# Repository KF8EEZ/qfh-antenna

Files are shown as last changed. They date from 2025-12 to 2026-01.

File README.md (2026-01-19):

[Published page](https://kf8eez.github.io/qfh-antenna/)

# QFH Antenna Notes

Originally interested in the idea because of this [Cornell project](https://crowdfunding.cornell.edu/project/44450) that recommended one for a TinyGS ground site.

## Calculator

This calculator is referred to everywhere:
<http://jcoppens.com/ant/qfh/calc.en.php>

But now appears to be down. However the internet arhive has it: <https://web.archive.org/web/20250915134142/https://jcoppens.com/ant/qfh/calc.en.php>

## VHF and UHF

- <https://uuki.kapsi.fi/qha.html#:~:text=The%20Quadrifilar%20Helical%20Antenna%20(QHA,ever%20find%2C%20in%20all%20directions>

## Designs for 433 MHz

- <https://www.thingiverse.com/thing:5878204/>
- <https://www.printables.com/model/787650-fullwave-compact-qfh-antenna-for-433mhz-band>
- <https://www.printables.com/model/1293002-qfh-antenna-for-435-mhz-satellites>

## GPS design L1 band

- <https://forum.allaboutcircuits.com/threads/diy-gps-module-qfh-antenna.110474/>
- <https://lea.hamradio.si/~s53mv/navsats/analog.html>
- <http://schripsema.org/pa3hdf/projects/gpsantenna/gpsantenna.html>
- <https://www.scribd.com/doc/61729826/A-Home-Made-Helical-Antenna-for-a-GPS>
  - apparently a screenshot from another link that is dead. 
  - I got my own [screenshot](/refs/2025-12-12-helical-capture.png)

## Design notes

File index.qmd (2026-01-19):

---
title: "Quadrafilar Helicoidal Antenna"
---

## Introduction

There are references and design information for a QuadraFilar Helicoidal (QFH) antenna. 

There is a [live calcuator](/live/qfhcalc.qmd) based on the highly cited work of [@jcoppens]. 

Originally interested in the idea because of this [Cornell project](https://crowdfunding.cornell.edu/project/44450) that recommended one for a TinyGS ground site.

## Links to specific designs

### VHF

- <http://www.rocob.plus.com/main.html>

### VHF and UHF

- <https://uuki.kapsi.fi/qha.html> [@Niskanen2026]

### Designs for UHF 433 MHz

- <https://www.thingiverse.com/thing:5878204/>
- <https://www.printables.com/model/787650-fullwave-compact-qfh-antenna-for-433mhz-band>
- <https://www.printables.com/model/1293002-qfh-antenna-for-435-mhz-satellites>
- <https://www.printables.com/model/759022-qfa-qfh-antenna-70cm-band/comments>

### 868 MHz

- <https://github.com/cernohorsky/QFH-Antenna-868MHz>

### GPS design L1 band

- <https://forum.allaboutcircuits.com/threads/diy-gps-module-qfh-antenna.110474/>
- <https://lea.hamradio.si/~s53mv/navsats/analog.html> [MatjazVidmar2026]
- <http://schripsema.org/pa3hdf/projects/gpsantenna/gpsantenna.html>
- <https://www.scribd.com/doc/61729826/A-Home-Made-Helical-Antenna-for-a-GPS>
  - apparently a screenshot from another link that is dead. 
  - I got my own [screenshot](/refs/2025-12-12-helical-capture.png)

### 2450 MHz

- <https://www.thingiverse.com/thing:634205>

## References

:::{#refs}
:::

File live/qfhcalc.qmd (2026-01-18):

---
title: QFH antenna calculator
format: live-html
pyodide:
  autorun: true
  packages:
    - numpy
    - pandas
    - scipy
---

This cacluator is based on the work of [@jcoppens]. The original web-page is not online as of 2026-01-18 so I wrote this page to perform the calculations. This is live python code, you can edit the code blocks and rerun the calculations for different antenna parameters in order to customize to your scenario.

::: {.callout-warning}
In the original javascript version, the speed of light was set to $3\times 10^8$ m/s. This code uses a more accurate value of $2.997\times 10^8$ m/s from `scipy` so the results will not be identical. I created a [verify page](/static/verify.qmd) which uses the less precise value for validation.
:::

## Pyodide setup

```{pyodide}
#| autorun: true
import numpy as np
import pandas as pd
from scipy.constants import speed_of_light
```

## QFH design parameters

This is the code block where you should set the vlaues for your antenna design.

```{pyodide}
#| autorun: true
frequency_MHz = 137.5 # antenna operating frequency, freq
number_turns = 1.0 # number of turns to antenna, turns
length_of_one_turn = 1.0 # measured in wavelengths, [0.25, 0.5, 0.75, 1.0] rwavel
bending_radius_mm = 15.0 # wrad 
wire_diameter_mm = 3.0 # diam? , wdiam ?
width_height_ratio = 0.44 # ratio
```

## Results

### Wavelength in freespace

```{pyodide}
#| autorun: true
wavelength = speed_of_light/(frequency_MHz*1e6) # meters, wavel
print(f'Wavelength = {wavelength} meters')
```

### Compensated wavelength

This is a correction for the size of the wire. 

```{pyodide}
#| autorun: true
wire_diameter_effective_mm = wire_diameter_mm
if wire_diameter_effective_mm > 15.0:
    wire_diameter_effective_mm = 15.0

def delta_length(diam):

    # this is a table of corrections copied directly from qfhcalc.js
    # the index appears to translate directly to the wire diameter in mm
    tbl = np.array([1.045, 1.053, 1.060, 1.064, 1.068, 1.070, 1.070, 1.071, 
             1.071, 1.070, 1.070, 1.070, 1.070, 1.069, 1.069, 1.068,
	     1.067])
    intv = int(np.floor(diam))
    dl = tbl[intv] +  (tbl[intv+1]-tbl[intv])*(diam-intv)
    return dl

compensated_wavelength = wavelength * delta_length(wire_diameter_effective_mm) # wavelc

print(f'Compensated wavelength = {compensated_wavelength} meters')
```

### Bending correction

```{pyodide}
#| autorun: true
#| label: bending-correction
bending_correction_mm = 2*bending_radius_mm - np.pi*bending_radius_mm/2.0 # bcorr

print(f'Bending correction = {bending_correction_mm} millimeters')
```

### Optimal conductor diameter

This is a confusing calculation in the original because it depends upon the conductor diameter.

```{pyodide}
#| autorun: true
#|label: optimal-conductor
# factor of 1000 converts meter to millimeter
# factor of 0.0088 is in original code, don't know what it is
optimal_diameter_mm = 0.0088 * compensated_wavelength * 1000.0

print(f'Optimal condcutor diameter = {optimal_diameter_mm} millimeters')
```

### Larger loop

This is also referred to as loop 1

```{pyodide}
#| autorun: true
#| label: larger-loop-values
total_length_lg = compensated_wavelength * 1.026 # total1
total_compensated_length_lg = total_length_lg + 4 * bending_correction_mm/1000 # total1c
horizontal_separator_lg =  0.5 *  total_compensated_length_lg/ \
           (1 + np.sqrt(1/width_height_ratio**2 + (number_turns*np.pi)**2)) # rad1, D1=
horizontal_compensated_separator_lg = horizontal_separator_lg - 2*bending_radius_mm/1000.0 # rad1c, D1C=
vertical_separation_lg = (total_compensated_length_lg - 2*horizontal_separator_lg)/2 # vert1
vertical_separation_compensated_lg = vertical_separation_lg - 2*bending_radius_mm/1000.0 # vert1c
internal_diameter_lg = horizontal_separator_lg - wire_diameter_mm/1000.0 #idiam1, Di1=
height_lg = horizontal_separator_lg / width_height_ratio # height1, H1=
```

```{pyodide}
#| autorun: true
#| label: print-large-loop-values
data_lg = {
    'Names': [
        'Total length',
        'Vertical separator',
        'Total compensated length',
        'Compensated vertical separation',
        'Antenna height',
        'Internal diameter',
        'Horizontal separator',
        'compensated horizontal separation',
        ],
    'Labels' :[
        '',
        '',
        '',
        '',
        'H1=',
        'Di1=',
        'D1=',
        'Dc1=',
        ],
    'Values': [
        total_length_lg,
        vertical_separation_lg,
        total_compensated_length_lg,
        vertical_separation_compensated_lg,
        height_lg,
        internal_diameter_lg,
        horizontal_separator_lg,
        horizontal_compensated_separator_lg,
        ]
    }
df = pd.DataFrame(data_lg)
df
```

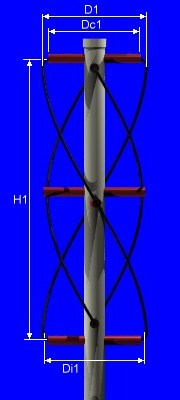
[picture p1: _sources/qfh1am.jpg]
Diagram of dimensions for larger loop from [@jcoppens]


### Smaller loop

This is also referred to as loop 2. These are basically the same calculations except for the 0.975 factor instead of the 1.026 factor.

```{pyodide}
#| autorun: true
#| label: smaller-loop-values
total_length_sm = compensated_wavelength * 0.975 # total2
total_compensated_length_sm = total_length_sm + 4 * bending_correction_mm/1000 # total2c
horizontal_separator_sm =  0.5 *  total_compensated_length_sm/ \
           (1 + np.sqrt(1/width_height_ratio**2 + (number_turns*np.pi)**2)) # rad2, D2=
horizontal_compensated_separator_sm = horizontal_separator_sm - 2*bending_radius_mm/1000.0 # rad2c, D2c=
vertical_separation_sm = (total_compensated_length_sm - 2*horizontal_separator_sm)/2 # vert2
vertical_separation_compensated_sm = vertical_separation_sm - 2*bending_radius_mm/1000.0 # vert2c
internal_diameter_sm = horizontal_separator_sm - wire_diameter_mm/1000.0 #idiam1, Di2=
height_sm = horizontal_separator_sm / width_height_ratio # height2, H2=
```

```{pyodide}
#| autorun: true
#| label: print-small-loop-values
data_sm = {
    'Names': [
        'Total length',
        'Vertical separator',
        'Total compensated length',
        'Compensated vertical separation',
        'Antenna height',
        'Internal diameter',
        'Horizontal separator',
        'compensated horizontal separation',
        ],
    'Labels' :[
        '',
        '',
        '',
        '',
        'H2=',
        'Di2=',
        'D2=',
        'Dc2=',
        ],
    'Values': [
        total_length_sm,
        vertical_separation_sm,
        total_compensated_length_sm,
        vertical_separation_compensated_sm,
        height_sm,
        internal_diameter_sm,
        horizontal_separator_sm,
        horizontal_compensated_separator_sm,
        ]
    }
df = pd.DataFrame(data_sm)
df
```

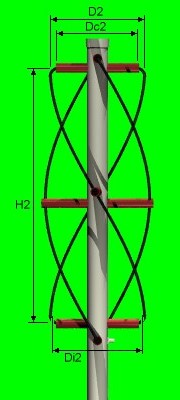
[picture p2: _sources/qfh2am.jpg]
Diagram of dimensions for smaller loop from [@jcoppens]


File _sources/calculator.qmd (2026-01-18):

This is based on <https://jcoppens.com/ant/qfh/calc.en.php> which now seems to be down but can be found on the internet archive at <https://web.archive.org/web/20250915134142/https://jcoppens.com/ant/qfh/calc.en.php>.

For testing of javascript in original, I used this page <https://jsconsole.com/>

## Python imports

Compute wavelength. Original website used $c=3\times 10^8$ m/s. For testing I'm using that value here. 

```{python}
import numpy as np
import pandas as pd
# from scipy.constants import speed_of_light
speed_of_light = 3e8 # m/s to match original for testing
```

## Design parameters

```{python}
frequency_MHz = 137.5 # antenna operating frequency, freq
number_turns = 1.0 # number of turns to antenna, turns
length_of_one_turn = 1.0 # measured in wavelengths, [0.25, 0.5, 0.75, 1.0] rwavel
bending_radius_mm = 15.0 # wrad 
wire_diameter_mm = 3.0 # diam? , wdiam ?
width_height_ratio = 0.44 # ratio
```

## Results

### Wavelength in free space

```{python}
wavelength = speed_of_light/(frequency_MHz*1e6) # meters, wavel
```

### Compensated wavelength

This is a correction for the size of the wire. 

```{python}
wire_diameter_effective_mm = wire_diameter_mm
if wire_diameter_effective_mm > 15.0:
    wire_diameter_effective_mm = 15.0
```

```{python}
#| label: compute-compensated-wavelength
def delta_length(diam):

    # this is a table of corrections copied directly from qfhcalc.js
    # the index appears to translate directly to the wire diameter in mm
    tbl = np.array([1.045, 1.053, 1.060, 1.064, 1.068, 1.070, 1.070, 1.071, 
             1.071, 1.070, 1.070, 1.070, 1.070, 1.069, 1.069, 1.068,
	     1.067])
    intv = int(np.floor(diam))
    print(intv,tbl[intv])
    dl = tbl[intv] +  (tbl[intv+1]-tbl[intv])*(diam-intv)
    return dl

compensated_wavelength = wavelength * delta_length(wire_diameter_effective_mm) # wavelc
    
```

### Bending correction

```{python}
#| label: bending-correction
bending_correction_mm = 2*bending_radius_mm - np.pi*bending_radius_mm/2.0 # bcorr
```

### Optimal conductor diameter

This is a confusing calculation in the original because it depends upon the conductor diameter.

```{python}
#|label: optimal-conductor
# factor of 1000 converts meter to millimeter
# factor of 0.0088 is in original code, don't know what it is
optimal_diameter_mm = 0.0088 * compensated_wavelength * 1000.0
```

### Larger loop

This is also referred to as loop 1

```{python}
#| label: larger-loop-values
total_length_lg = compensated_wavelength * 1.026 # total1
total_compensated_length_lg = total_length_lg + 4 * bending_correction_mm/1000 # total1c
horizontal_separator_lg =  0.5 *  total_compensated_length_lg/ \
           (1 + np.sqrt(1/width_height_ratio**2 + (number_turns*np.pi)**2)) # rad1, D1=
horizontal_compensated_separator_lg = horizontal_separator_lg - 2*bending_radius_mm/1000.0 # rad1c, D1C=
vertical_separation_lg = (total_compensated_length_lg - 2*horizontal_separator_lg)/2 # vert1
vertical_separation_compensated_lg = vertical_separation_lg - 2*bending_radius_mm/1000.0 # vert1c
internal_diameter_lg = horizontal_separator_lg - wire_diameter_mm/1000.0 #idiam1, Di1=
height_lg = horizontal_separator_lg / width_height_ratio # height1, H1=
```

```{python}
#| label: print-large-loop-values
data_lg = {
    'Names': [
        'Total length',
        'Vertical separator',
        'Total compensated length',
        'Compensated vertical separation',
        'Antenna height',
        'Internal diameter',
        'Horizontal separator',
        'compensated horizontal separation',
        ],
    'Labels' :[
        '',
        '',
        '',
        '',
        'H1=',
        'Di1=',
        'D1=',
        'Dc1=',
        ],
    'Values': [
        total_length_lg,
        vertical_separation_lg,
        total_compensated_length_lg,
        vertical_separation_compensated_lg,
        height_lg,
        internal_diameter_lg,
        horizontal_separator_lg,
        horizontal_compensated_separator_lg,
        ]
    }
df = pd.DataFrame(data_lg)
df
```

### Smaller loop

This is also referred to as loop 2. These are basically the same calculations except for the 0.975 factor instead of the 1.026 factor.

```{python}
#| label: smaller-loop-values
total_length_sm = compensated_wavelength * 0.975 # total2
total_compensated_length_sm = total_length_sm + 4 * bending_correction_mm/1000 # total2c
horizontal_separator_sm =  0.5 *  total_compensated_length_sm/ \
           (1 + np.sqrt(1/width_height_ratio**2 + (number_turns*np.pi)**2)) # rad2, D2=
horizontal_compensated_separator_sm = horizontal_separator_sm - 2*bending_radius_mm/1000.0 # rad2c, D2c=
vertical_separation_sm = (total_compensated_length_sm - 2*horizontal_separator_sm)/2 # vert2
vertical_separation_compensated_sm = vertical_separation_sm - 2*bending_radius_mm/1000.0 # vert2c
internal_diameter_sm = horizontal_separator_sm - wire_diameter_mm/1000.0 #idiam1, Di2=
height_sm = horizontal_separator_sm / width_height_ratio # height2, H2=
```

```{python}
#| label: print-small-loop-values
data_sm = {
    'Names': [
        'Total length',
        'Vertical separator',
        'Total compensated length',
        'Compensated vertical separation',
        'Antenna height',
        'Internal diameter',
        'Horizontal separator',
        'compensated horizontal separation',
        ],
    'Labels' :[
        '',
        '',
        '',
        '',
        'H2=',
        'Di2=',
        'D2=',
        'Dc2=',
        ],
    'Values': [
        total_length_sm,
        vertical_separation_sm,
        total_compensated_length_sm,
        vertical_separation_compensated_sm,
        height_sm,
        internal_diameter_sm,
        horizontal_separator_sm,
        horizontal_compensated_separator_sm,
        ]
    }
df = pd.DataFrame(data_sm)
df
```

## Original

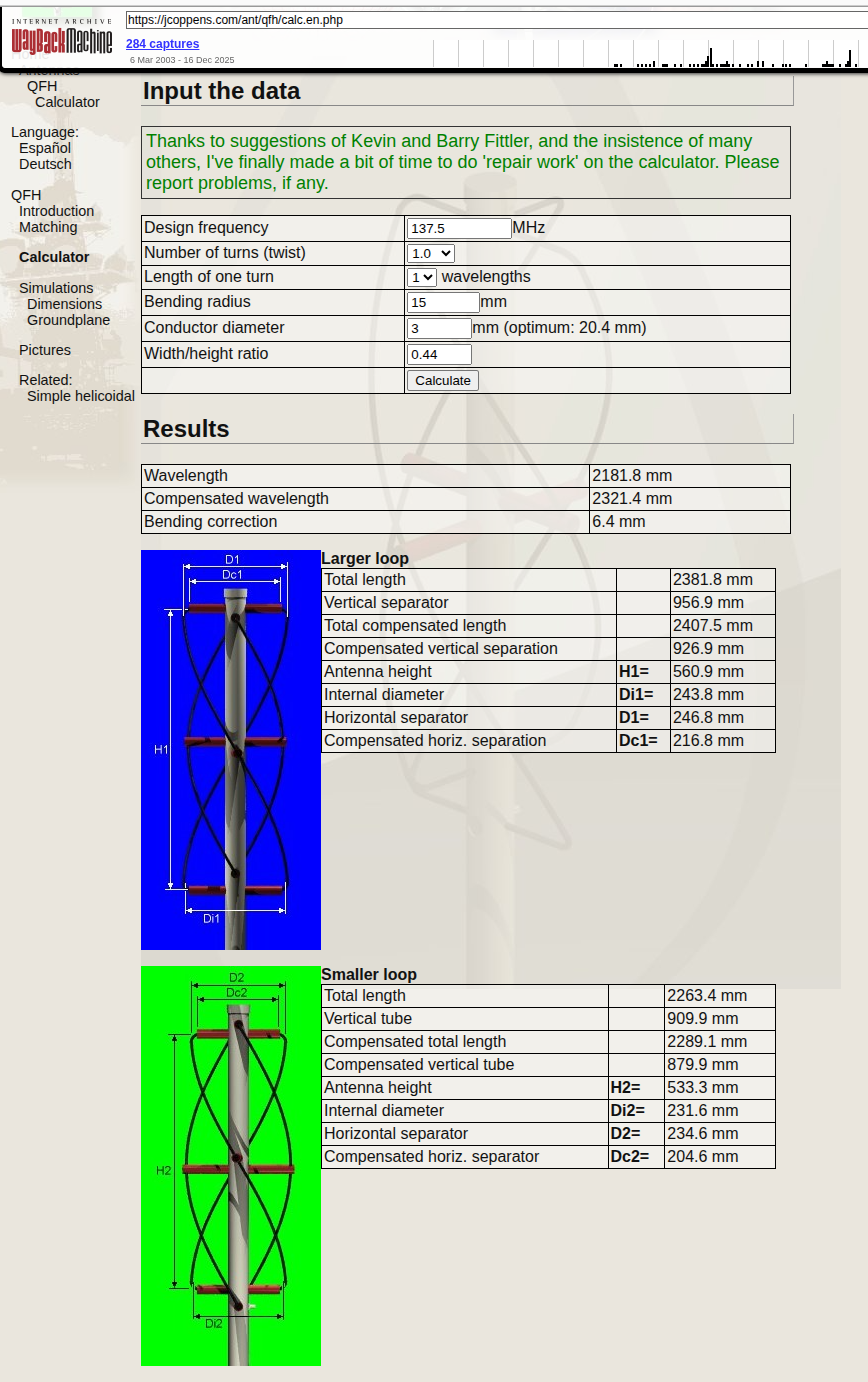
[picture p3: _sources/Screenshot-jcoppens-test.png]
Screenshot of original page captured by internet archive using the same parameters in this page.


### Legend of parameters copied from original

This calculator generates a lot of data! Take care in the use of the information in order not to make mistakes...
Here's a little explanation:

- Design frequency
  - Evident?
- Number of turns (twist)
  - What's the twist of the antenna? (normally 0.5 (180 degrees)
- Length of one turn
  - A few variations of the antenna exist. Normally the circumference (length of the loop) is 1 wavelength, but 1.5 wavelength and 2 wavelength versions exist.
- Bending diameter
  - As it's impossible to bend the corner abruptly at 90 degrees, this value is needed for the calculations. It's measured from the bending center to the center of the tube.
- Conductor diameter
  - External diameter of the tube or coax cable.
- Diameter/height ratio
  - Most frequently this ratio is 0.44, but slightly lower values (0.3 to 0.4) give better horizon coverage.
- Wavelength
  - Wavelength, corresponding to the selected frequency.
- Compensated wavelength
  - Wavelength, compensated according to the conductor diameter.
- Bending correction
  - Correction value needed according to the bending diameter.
- Total length
  - Total length of the loop, before compensation.
- Total loop cmpensated length
  - Total length of the loop, compensated for the bending effect, and the fact that the loop must be slightly larger (or smaller). This is the amount of tubing necessary for this loop.
- Compensated vertical separation
  - Vertical separation (without the 'bends').
- Compensated horizontal separation
  - This is in fact the horizontal part without the 'bends', and corresponds to the horizontal pipe necessary to support the cable.
- Antenna height
  - Height of the loop (twisted!).
- Internal diameter
  - The diameter of the (imaginary) cylinder on which the loop would be wound.

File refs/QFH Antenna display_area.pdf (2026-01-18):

## QFH Antenna (The Quadrifilar Helical antenna)

provides circular polarization and complete hemispherical reception, which is precisely what is needed to receive the polar orbiting weather satellites, and as a

### 2 meter antenna it will receive horizontal, vertical and clockwise circular

polarization’s from all directions. Fig 1. illustrates the antenna which consists of two vertical loops at right angles to each other, resonant at slightly different frequencies, twisted into a half turn helix. Correctly made it will provide true
all round coverage with circular polarization at all angles. The usual crossed
dipoles and reflectors used for satellite reception only provide circular polarization directly upwards when the signal strength is high anyway, at low angles when maximum sensitivity is required the polarization is linear, losing 3 dB on the circularly polarized satellite signal. In addition Quadrature feed of crossed dipoles to achieve circular polarization is beautiful in theory and almost impossible to achieve in practice.

Bob Cobey G0HPO an avid weather satellite fan first made one in this area and reported phenomenal results, even inside the roof space of his bungalow. Good noise free pictures were received from Greenland through to Algeria.

The R.I.G articles by Mark Pepper Rig 37 and Chris Van Lint (Rig 44) and also in QST are based on the original work by NASA featured in the ARRL Antenna handbook. There are a number of practical problems in the design which have been addressed and solved over many weeks of computer modelling and prototype construction.

The computer generated (Azimuth & Elevation) polar diagrams are of course perfection and a series of actual measurements of the horizontal and vertical patterns were undertaken on the final design to confirm the computer results.

The measured vertical and horizontal polar diagrams using clockwise polarization, were produced using the latest version of a program by Bob Freeth ( G4HFQ ) called PolarPlot. The Windows 95/98 & 2000 version of the program is now available for download by visiting his page using the links in the right hand column.

Vertical and horizontal polarization’s are 3dB down on clockwise as expected and the horizontal pattern is still circular. The polar diagram in the vertical plane is particularly useful, showing very little reception from below, thus reducing the formation of nulls caused

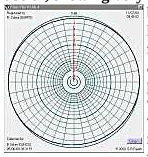
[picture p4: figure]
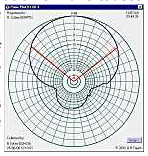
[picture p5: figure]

by ground reflections. There are no nulls in the horizontal pattern at any polarization. Allowing for slight distortion in actual measurement of antenna performance, caused by the usual site problems the measured plots and measured gain were identical to the computer generated plots which was particularly satisfying, given the inherent difficulty in modelling a helix in XYZ format for the computer.

The major problem is how to make the beast, and particularly how to make it weatherproof. Firstly the dimensions given by the NASA based articles need to be adjusted for weather satellite and 2 meter frequencies. The diameter of tubing used in the ARRL handbook works

Larger Views may be seen by Clicking on the side index or the pictures

1/18/26, 2:30 PM | QFH Antenna display_area
www.rocob.plus.com/main.html | 1/4

out to 19mm at 137 MHz and dimensions show the INSIDE diameter of the helix. Conversion to 8mm tubing which is a much more sensible size at 137 and 145 MHz was not just a question of simple scaling. As stated in the book a quadrature-phase current relationship is required between the two loops. This is achieved by making one loop larger than the desired frequency resonant length and therefore inductive, while the other loop is smaller and therefore capacitive. Correct resonance of each loop means that a circular pattern may be achieved by simply connecting the two loops in parallel. This is confirmed in practice when the SWR dips once only at the required frequency. It is all too easy to get a double hump response which is incorrect, and will show a figure of eight pattern rather than a true circular horizontal polar diagram. The sizes shown have been confirmed by computer modelling and actual measurements on the prototype, and do not conform with the book figures. In particular the helix should be the same diameter throughout its length and therefore the length of the arms forming the helix is important. The formula for this length
is | where 'r' is the radius and 'h' the height of the helix.

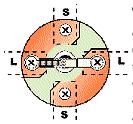
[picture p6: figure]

The major problem was how to make weatherproof the connections at top and bottom of the helix. The connections at the top of the helix in the original design were almost impossible, as the connection had to be made to the ends of four tubes, two of which were 24mm below the top two, with all inside the support mast. Using the computer modelling program, various connection methods were tried to establish a sensible method without compromising the performance. It proved possible to slope the tops of the small loop so that all four tube ends were in a common plane at the top of the mast where they can be reached. The final method uses a small piece of PC board very simply made, shown in Fig 2, which gives good mechanical and electrical connections.

Fig 3 illustrates the original infinite balun arrangement which provides an
elegant way of bringing the feeder away from the antenna at a voltage null.
This is totally impossible to make if the antenna is made using a central non metallic support mast (as it must be at 137 MHz) when the connections would have to be made inside the mast.
One solution to this was to make the antenna from two continuous lengths of
copper tubing with a small diameter coaxial feeder brought through a hole in
the feed tube at the null point and connected at the top. This would still be difficult as the feeder entry hole would be inside the support mast. In practice moving the hole a few millimetres to bring the feeder outside the mast solves the mechanical problem and since the current in the lower half of the loop is substantially constant, still provides a good enough voltage null to get the feeder away without affecting the performance of the antenna. The outer braiding of the coax need not be connected to the tube at the point of exit thus preserving the integrity of the coax for weatherproofing. Several antennas were built using this method and were perfectly satisfactory electrically, but construction was extremely difficult. Various methods of actually making the Helix were tried, the use of coaxial cable as in previous designs is acceptable as an indoor antenna but weatherproofing for outside use is almost impossible. 8mm soft copper central heating tube available from the plumbing department of all DIY shops and builders merchants proved to be the easiest to use. Bending tubing by hand is not satisfactory unless the resulting kinks and flattening are acceptable. The elegant way is to use small copper elbows at the corners but it proved totally impossible to insert RG58 coax into the tube after the elbows had been sweated into position and sweating after the coax was inside was not a good idea.
While the original balun design is perfection electrically, it is the main cause of the construction difficulties, and some other type of balun was required. The use of a simple choke balun proved to be the answer and solved all the mechanical problems.
Fig.4 illustrates the feed method where the necessary isolating choke is formed from winding

### 4 turns of the feeder cable round the support mast. No longer does the antenna have to be

www.rocob.plus.com/main.html | 2/4

constructed from coaxial cable or have coaxial cable threaded through tubes, and it CAN BE MADE with identical performance to the original NASA design. Performance checks comparing the original design with the new system showed no differences, in particular the feeder was still dead.

CONSTRUCTION

Fig.5 shows the final design using 8mm copper tube with dimensions shown as cut lengths for 137.55 MHz allowing for the length of the copper elbows. Any change in tube size will require different dimensions. Make no mistake, the dimensions are important. This antenna will work after a fashion with almost any slip shod construction but then the polar diagram will not be circular and its a matter of luck whether the maximum lobes are in a useful position.

Mark out the plastic support mast using the template Fig 6 to
ensure that the holes are at right angles. Drill the 4 x 8mm holes,
two at the top at right angles in the same plane and the two lower down at right angles spaced 24mm. Then drill the 7 mm hole near the top of the mast for the cable entry as shown in fig 4.
Carefully straighten the roll of 8mm tube. This is best done by rolling it out onto the floor keeping the coil vertical. Cut the tube into lengths to the dimensions shown and drill the appropriate holes for the self tapping screws in the ends of the top horizontal sections.
Firstly make the top part of the antenna with the cable and connections. Feed the coax through the hole into the mast and then out of the top threading it through the hole in the centre of the PC board. The top 4 horizontal tubes can then be assembled, the two horizontal tubes forming the top of the smaller of the two loops should be carefully bent 24mm see Fig.

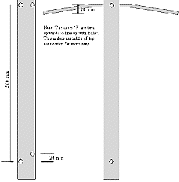
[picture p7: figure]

### 7. The PC board should be mounted copper side down to connect

with the copper of the tubes, thus avoiding any dissimilar metal
problems with the possible zinc plating of the screws. Four turns
of the feeder cable should now be wound around the support mast to form the balun and taped into position.
Next mount the lower 2 horizontal sections through the mast positioning them centrally. The helix can now be formed. First place the copper elbows into position but do not solder at this stage. Carefully bend the appropriate lengths of tube to form the
helix. Remember the helix should be wound ANTICLOCKWISE
as seen from the top (and the bottom for that matter) to provide
clockwise polarization as used on the weather satellites. Final soldering into place can now be done using a small gas torch, the plumbers’ trick of applying flux to the copper tubes before fitting onto the elbows will ensure quick and easy flow of solder. The connections at the top require an end cap for weatherproofing and although the appropriate pieces can be obtained from the same source as the plastic tube the user may well find a plastic jar cover of suitable size to do the job.

PLEASE REMEMBER THAT THIS TYPE OF ANTENNA PRESENTS A DC SHORT CIRCUIT AND PRECAUTIONS SHOULD BE TAKEN IF YOUR RECEIVER OUTPUTS A VOLTAGE TO FEED A PRE-AMP.

Cut lengths in mm for 137.55 MHz, using 8mm Central Heating tube & 90 deg elbows.

LOOP | A | B | C | D | E | F | Ht. | PERI
Large | 2 x 812 | 1 x 374 | 2 x 182 | | | | 560 | 2418
www.rocob.plus.com/main.html | 3/4

Small | 2 x 758 | 1 x 356 | 2 x 178 | 512 | 2284

Parts List (Cost less than £15 from most Hardware Stores)

### 5 mtr x 8 mm Copper Tube (Mini Bore Central Heating Pipe) 8 x 8 mm 90 Deg. End Fed Elbows ( Qty. 8 required ) 1 meter of 32 mm PVC waste pipe

Etched PC board or Strip board with strips cut to suit.
4 Self start screws to secure PCB and feed.
Suitable length of UR43 or RG58 Coaxial cable for Balun and feed

© G0HPO July 2000 - September 2003

www.rocob.plus.com/main.html | 4/4

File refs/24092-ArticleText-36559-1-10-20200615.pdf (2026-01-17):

International Journal of Advance Science and Technology Vol. 29, No. 10S, (2020), pp. 7694-7705

ISSN: 2005-4238 IJAST | 7694
Copyright ⓒ 2020 SERSC

### SDR Based Ground Station for Image Reception from Weather Satellites

Ajith Kumar Joel T¹

, Pavan Kalyan Reddy Y²

, Charan Yadav NP³

, Chandan MN⁴
, Dr.
M.Devanathan⁵
1,2,3School of ECE REVA University Bangalore, India Asst. Prof., School of ECE REVA University Bangalore, India ajith1081999@gmail.com¹

, pavankalyan29787@gmail.com²

, npcharan77@gmail.com³
chandanmn183@gmail.com⁴

, Devanathan.m@reva.edu.in⁵

Abstract
From the specific view of space, sophisticated Low Earth Orbit (LEO) satellites provide us with information on cloud movements, precipitation, land and sea surface temperatures. These satellites are fascinating as they continuously transmit an image signal that is easy to decipher of what they are actually looking at. This data is useful to predict weather and rainfall. The main purpose of this work is to develop an inexpensive ground station for receiving the images from these satellites and give a rough prediction of weather and rainfall. Software Defined Radio (SDR) was used for the reception of these signals along with V-Dipole, QFH Antenna and several open source software’s. So far this work is successful in receiving signal from 40+ satellite passes of the National Oceanic and Atmospheric Administration’s (NOAA) and METEOR-M2 satellites over the location Bangalore, India (Grid: MK83SC) and decoded the same to obtain real time images as seen by the satellite. The images obtained were further analyzed for rough weather predictions over the above mentioned location.

Keywords: Automatic Picture Transmission (APT), Low Rate Picture Transmission (LRPT), Software Defined Radio (SDR), Quadrifilar Helix (QFH) Antenna.

### 1. INTRODUCTION

The National Oceanic and Atmospheric Administration’s (NOAA) is an American scientific agency which has launched 19 satellites that focuses on forecasting changes in climate, weather, oceans and coasts. At present NOAA-15, NOAA-18 and NOAA-19 are geosynchronous satellites active with Automatic Picture Transmission (APT) feature, orbiting at an altitude around 830km. These satellites are equipped with series of instruments and one of the sensor which is AVHRR (Advanced Very High-Resolution Radiometer) has a feature to detect the reflection of electromagnetic waves by clouds, surface waters and objects on the surface of the earth. The AVHRR has 6 detectors operating on a channel of wavelengths ranging from visible to thermal infrared. The live weather images are broadcasted by the APT signals. METEOR-M2 is a Russian weather satellite launched to monitor atmosphere, sea temperatures, humidity, ice conditions and clouds. Meteor-M2 is currently active with LRPT (Low Rate Picture Transmission) feature. The objective is to set up a low cost base station by using a Software Defined Radio (SDR) along with a suitable antenna (Quadrifilar Helix Antenna, V Dipole Antenna ) to receive the signals from NOAA and Meteor-M2 satellites and decode the same using several open source software's (SDR#, WxToImg, Orbitron, LRPT Decoder) to obtain real time images when the satellite is overhead.

### 2. AUTOMATIC PICTURE TRANSMISSION(APT)

The Automatic Picture Transmission (APT) is an analog transmission system developed to get data in the form of pictures from weather satellites. Over five decades, it has helped to get real-time image data for low-cost base stations across many parts of the world. APT system has 2 image channels i.e. Infrared and Near Infrared/Visible Channel. The image reception starts when the receiver is within the radio range. For about 8-15 minutes the satellite is within the radio range. When both, the receiver and satellite frequencies are matched, with the help of unsophisticated receivers the final output is obtained.
Frequency range – 137-138 MHz

Bandwidth - 35 KHz (to overcome Doppler Shift) Modulation – Wideband FM (WFM)
Currently, there are only 3 NOAA satellites i.e. NOAA-15, NOAA-18 and NOAA-19 which transmit APT signals.

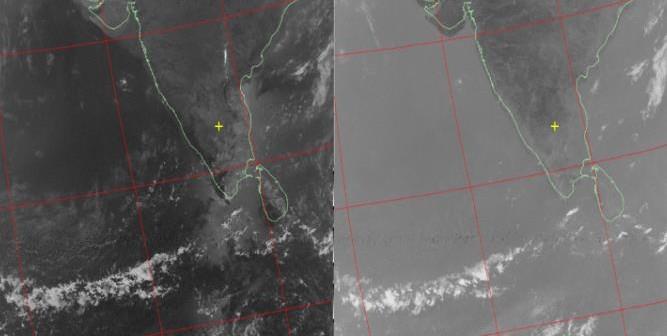
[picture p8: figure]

Fig 1: The 2 channel APT image system

### 3. LOW RATE PICTURE TRANSMISSION (LRPT)

The Low Rate Picture Transmission (LRPT) is a digital transmission system, which is used by the Meteor-M2 satellite to transmit the signal. This system was introduced as a replacement for APT. APT system had only 2 image channels (Infrared and Near Infrared/Visible Channel) which were at reduced accuracy and resolution (8-bit, 4km/pixel, 2 lines/second). LRPT system provides 3 image channels (RGB channels) with better resolution (10-bit, 1km/pixel, 6 lines/second). Frequency range - 137-138 MHz
Bandwidth - 120 KHz (to overcome Doppler Shift) Modulation – Quadrature Phase Shift Keying (QPSK)

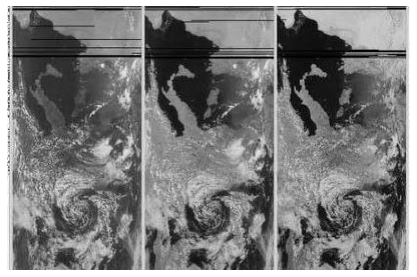
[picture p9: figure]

Fig 2: The 3 channel LRPT image system

Compared to APT, LRPT images contain 12 times the resolution and are 4 times more accurate.

### 4. IMPLEMENTATION

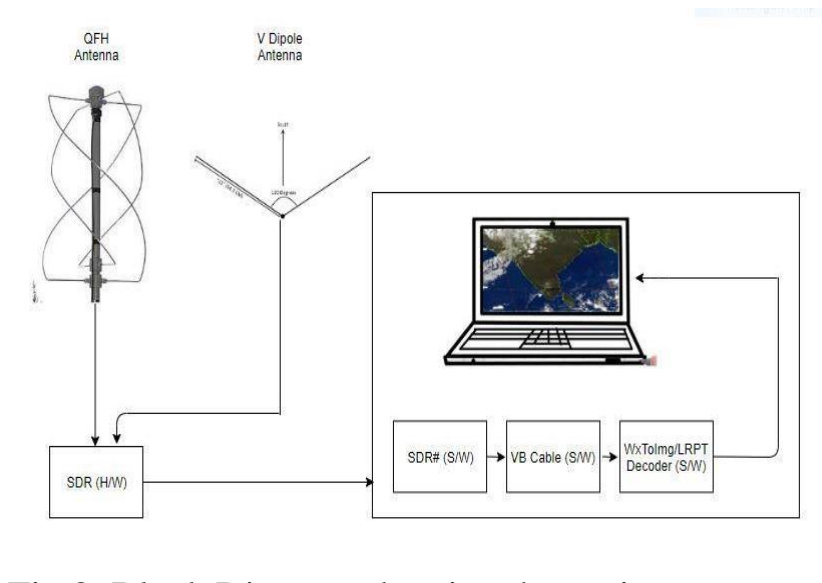
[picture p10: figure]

Fig 3: Block Diagram showing the project setup

The above block diagram shows the implementation of setting up a low-cost ground station for receivingthe signal from the weather satellites and decode the same using open source software’s. Setup consists of an antenna (only one is used at a time) which is connected to the RTL-SDR dongle. A RG-58 coaxial cable is used for the connections, one end of the coaxial cable is soldered to the antenna, the other end is connected to the SDR by means of two connectors viz. BNC male connector and BNC female to SMA male connector. Once these connections are done, the SDR is plugged into the USB port of the PC/Laptop.

A. Hardware Requirements
Based on the investigations done, the appropriate antennas that can be used for receiving APT and LRPT signals are V- Dipole Antenna, QFH (Quadrifilar Helix) Antenna, Double Crossed Antenna and Turnstile Antenna.
Here, the V-Dipole Antenna and the QFH Antenna are used along with a Software Defined Radio (SDR) for the signal reception from the weather satellites.
V- Dipole Antenna:
Initially the signal reception was done using a home-made V- Dipole antenna. A V-Dipole antenna is a simple linearly polarized λ/2 dipole separated by an angle of 120°. A conducting material such as copper is used for designing the dipole, here a 10 Standard Wire Gauge (SWG) copper wire is used whose length is determined by the formula[11] L= λ/2 where λ is the wavelength.
The wavelength λ is determined by using the formula c= λ.f, where c is the speed of light (approximated at 3*10^8m/s), f is the frequency and λ is the wavelength.
Let us choose f= 137.5MHz since the downlink frequencies of NOAA and Meteor-M2 satellites ranges from 137.1MHz to 137.9125MHz. Upon substituting f in the formula c= λ.f we get λ=2.1818m. Using this the length of the dipole is determined which is 2.1818/2= 1.0909m. Therefore the length of each leg should be approximately 54cm.

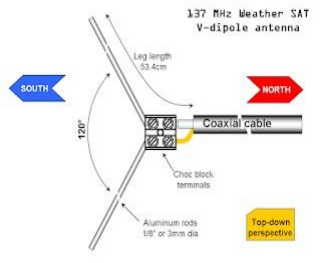
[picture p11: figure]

Fig 4: Schematic of the V-Dipole Antenna [11]

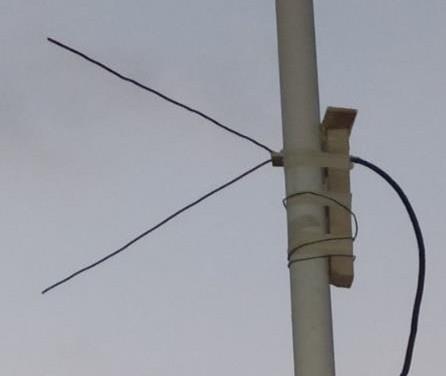
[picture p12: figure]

Fig 5: Constructed and Mounted V-Dipole Antenna

1. QFH (Quadrifilar Helix) Antenna:

One major drawback with using V-Dipole Antenna was that, depending on the direction of the satellite pass i.e. northbound or southbound, the antenna facing direction had to be changed to receive signal in the direction of the satellite pass. Therefore, to overcome this drawback, a circularly polarized QFH Antenna was built.
The Quadrifilar Helix (QFH) antenna is a Right Hand Circular Polarized (RHCP) antenna used for receiving signals from geosynchronous satellites. It consists of 2 loops whose dimensions are decided by the wavelength of the signal. The formula[10] for calculating the loop elements are:
Big Loop: | Small Loop:
Height= 0.26 λ | Height=0.238 λ
Diameter=0.173 λ | Diameter=0.156 λ
Leg Size=0.560 λ | Leg Size=0.508 λ

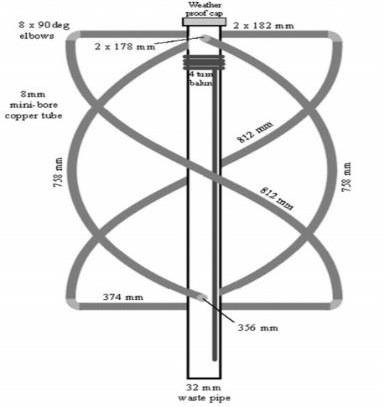
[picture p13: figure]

Fig 6: Schematic of the QFH Antenna [10]

The wavelength is calculated by using the following equation c= λ.f. In this equation c is the speed of light (approximated at 3*10^8m/s), f is the frequency and λ is the wavelength.
Since the downlink frequencies of NOAA and Meteor-M2 satellites are ranging between 137.1MHz-137.9125MHz let us choose the frequency f as 137.5MHz. Upon substituting f in the expression c= λ.f, we get λ=2.1818m. Using this value of λ we obtain the height, diameter and leg size of the 2 loops of the QFH antenna using the formulas listed above. A 14 Standard Wire Gauge (SWG) copper tube having outer diameter of 3/8 inch is used along with a PVC pipe for constructing the antenna.

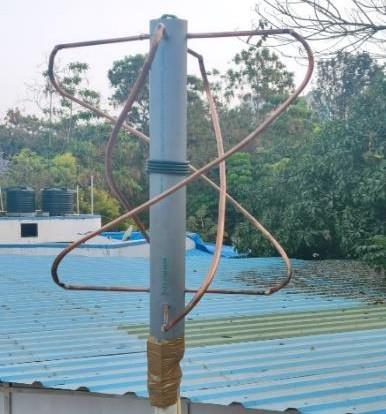
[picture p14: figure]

Fig 7: Constructed and Mounted QFH Antenna

2. Software Defined Radio (SDR):

Software-defined radio (SDR) is a system used for radio communication where hardware like amplifiers, filters, mixers, modulator/demodulator etc. implemented by traditional hardware like resistors, capacitors are instead implemented by embedded systems i.e. a chipset fabricated and mounted on a PCB. The SDR used here is a RTL-SDR manufactured by RTL- SDR Blog, it consists of the RTL2832U chipset which gives us access to the radio spectrum thereby enabling us to listen to frequencies ranging from 500KHz-1.5GHz. The RTL- SDR has a maximum sampling rate of 3.2 MS/s (Mega Samples per Second), however for weather satellite image reception it is operated at 2.4

MS/s. The input impedance of the RTL-SDR is approximately 75ohms.

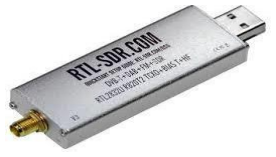
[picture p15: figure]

Fig 8: The RTL-SDR Dongle [12]

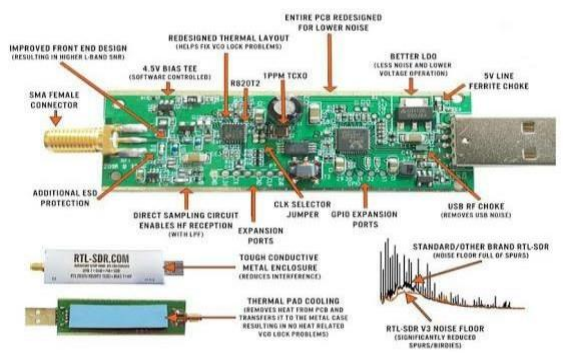
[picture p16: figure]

Fig 9: The internal structure of RTL-SDR [12]

B. Software Requirements
All the software’s used for the receiving and decoding the signals are open source software’s which doesn’t require any license for using them.
1. Zadig:
To get the RTL-SDR dongle running on a Windows OS, a driver is necessary for the installation. Zadig is a device driver software used for installing and configuring the RTL- SDR on the PC/Laptop. When the RTL-SDR dongle is plugged into the USB port for the first time, the zadig software has to be run to complete the installation of the dongle.
2. SDR Sharp (SDR#):
SDR Sharp (SDR#) is a PC-based DSP application used for Software Defined Radio (SDR). It is an open source software designed using C# language. The main purpose of using SDR# is to tune the receiving frequency of the SDR. Apart from these other parameters such as modulation type, bandwidth, RF gain, sampling frequency etc. can be varied as required. It also shows a waterfall diagram or frequency spectrum of the signal where the signal pattern can be analyzed.
3. WxToImg:
WxToImg is the software used for decoding the signal i.e. the audio received from the SDR# software is decoded into real time images as seen by the satellite. A 2 channel (Infrared and Near-Infrared/Visible) raw image is obtained which can be enhanced using various enhancement modes like MCIR (Map Colored IR Enhancement), MCIR precipitation, MSA (Multi Spectral Analysis), MSA precipitation, Thermal image, Sea surface Temperature etc.
4. Virtual Audio Cable (VB Cable):
The audio from the SDR# cannot be fed directly into the WxToImg via the PC’s mic as the external noises will be also picked up with the actual audio signal from the satellite. To overcome this the VB Cable software is used which pipes the

audio internally from SDR# to WxToImg so that no external noises are added to the original audio signal.

5. LRPT Decoder:
As the NOAA satellites works on the principle of Automatic Picture Transmission (APT), WxToImg software is sufficient for the decoding of the signal into image. But the Meteor-M2 satellite works on the principle of Low Rate Picture Transmission (LRPT), since WxToImg does not support decoding of LRPT signals, the LRPT Decoder software is used for decoding the Meteor-M2 satellite’s audio signal into image. Here a 3 channel (R,G,B or R,G,Infrared) raw image is obtained.
6. Orbitron:
The Orbitron is a satellite tracking software. It can be used to predict the passes of all active satellites over any location. It also gives the status of the satellite like elevation angle, azimuthal angle, maximum elevation, uplink frequency, downlink frequency etc. The Orbitron can also be used to auto-start the decoding by launching the SDR# and WxToImg software’s as soon as there is a satellite pass over the specified location with some minimum elevation
C. Procedure for receiving and decoding the signal:
- The Zadig software is launched in the PC to complete the installation of the RTL-SDR dongle. Now the SDR is configured and it isready to receive the signal from the antenna.
- Firstly, the Orbitron software is run, which gives the satellite’s pass information such as pass start time, pass end time, max. elevation, downlink frequency etc.
- The frequency in the SDR# software is tuned to the downlink frequency of the respective satellite. The required modulation type is selected (WFM for NOAA satellites, QPSK for Meteor-M2 satellite) and bandwidth is adjusted depending upon the signal type to be received. Once the play button is selected, the software starts receiving the signal.
- Along with the SDR#, simultaneously WxToImg
/LRPT Decoder is made to run. The audio output of the PC/Laptop is changed to VB Cable under the Control Panel. When the elevation of the satellite is greater than 10°, the WxToImg/LRPT Decoder starts decoding the audio signal received from SDR# into a raw image. Once the decoding is finished the raw image can be enhanced as per requirements of the user.

### 4. RESULTS AND DISCUSSION

Results
Among the 40+ satellite passes that has been attempted to receive signal and decoded to obtain from which received signal gave a good SNR (max. SNR at least greater than 25db) and the decoded image showing vast area coverage are shown in the table below along with the pass details.images, few passes has been selected

Table I. Images Received From Satellites

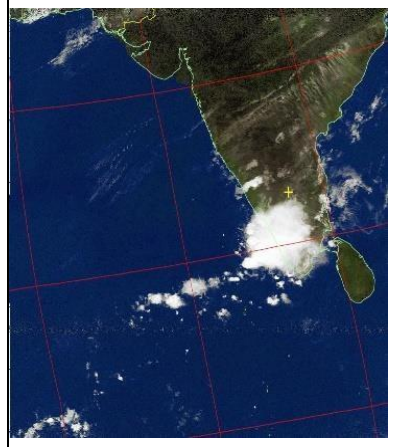
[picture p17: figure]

1) Antenna used: QFH | Antenna Satellite: NOAA-15 Date: 07/04/2020 Pass start: 07:54 IST Max elevation: 46.8° Direction: Northbound Grid: MK83SC (Bangalore, India) Enhancement applied: MCIR (Map colored IR) Enhancement

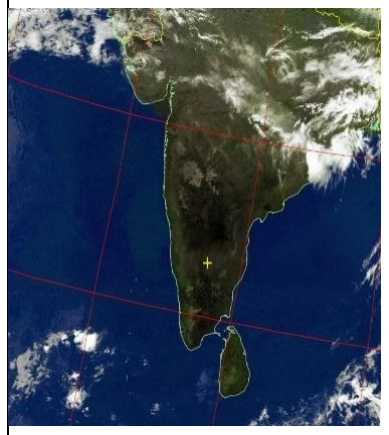
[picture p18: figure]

2) Antenna used: QFH | Antenna Satellite: NOAA-18 Date: 15/03/2020 Pass start: 21:16 IST Max elevation: 62° Direction: Northbound Grid: MK83SC (Bangalore, India) Enhancement applied: MCIR (Map colored IR) Enhancement

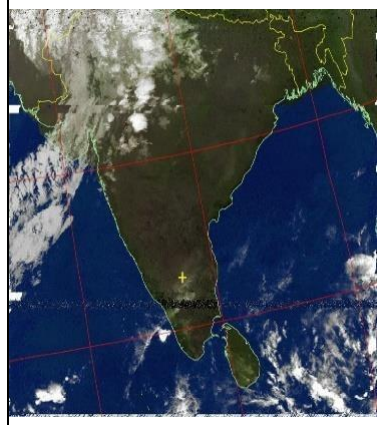
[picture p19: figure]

3) Antenna used: QFH | Antenna Satellite: NOAA-19 Date: 27/03/2020 Pass start: 05:58 IST Max elevation: 83.2° Direction: Northbound Grid: MK83SC (Bangalore, India) Enhancement applied: MCIR (Map colored IR) Enhancement

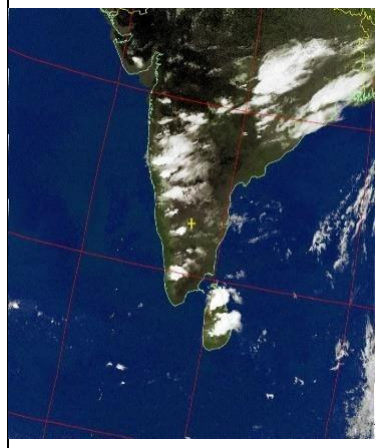
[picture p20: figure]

4) Antenna used: V- | Dipole Antenna Satellite: NOAA-19 Date: 10/04/2020 Pass start: 17:46 IST Max elevation: 84° Direction: Southbound Grid: MK83SC (Bangalore, India) Enhancement applied: MCIR (Map colored IR) Enhancement
No. | Pass Details | Image
5) Antenna used: QFH | Antenna Satellite: Meteor-M2 Date: 03/04/2020 Pass start: 08:55 IST Max elevation: 49.1° Direction: Northbound Grid: MK83SC (Bangalore, India)
6) Antenna used: V- | Dipole Antenna Satellite: Meteor-M2 Date: 21/04/2020 Pass start: 07:55 IST Max elevation: 32° Direction: Southbound Grid: MK83SC (Bangalore, India)

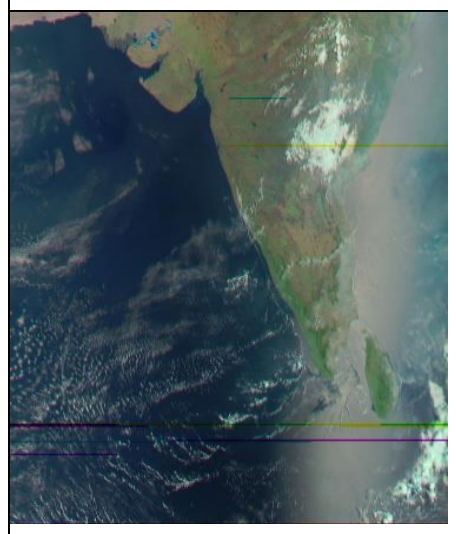
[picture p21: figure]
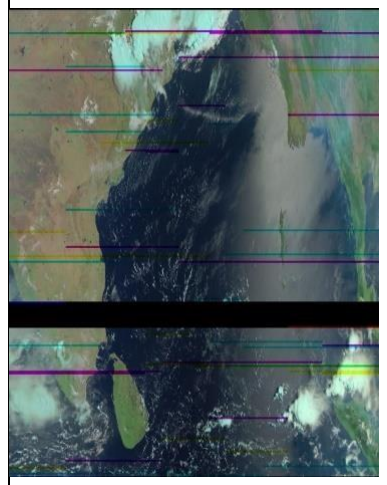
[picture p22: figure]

Discussion
One pass, each from NOAA and Meteor-M2 satellite is considered, and the detailed analysis of the image received is as shown below.

Considering the NOAA-15 satellite pass dated 07/04/2020
at 07:54 IST having a maximum elevation of 46.8° and heading northbound, shown below are the images obtained after applying different enhancement methods to the raw image received from the decoded audio signal via the WxToImg software.

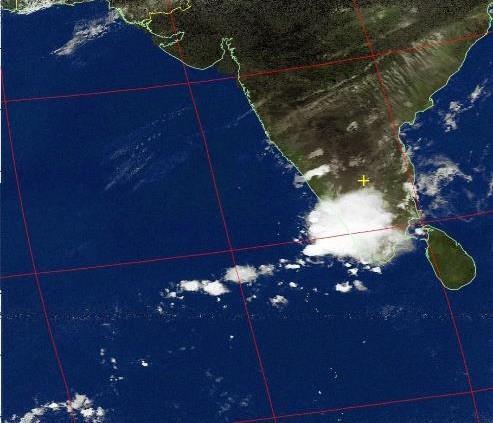
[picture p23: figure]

Fig 10: MCIR (Map Colored IR) Enhancement

Fig 10 shows the MCIR Enhancement applied to the raw image. Through this MCIR enhancement a colored image is obtained which is near equivalent to what is seen by the satellite in the real time. A cloud formation is seen over the southern parts of India roughly covering parts of Kerala, Tamil Nadu and Karnataka.

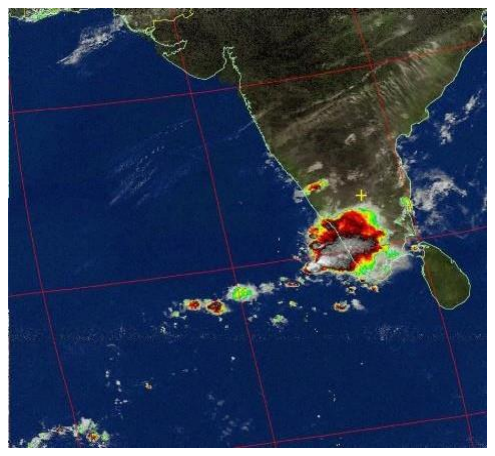
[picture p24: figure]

Fig 11: MCIR (Map Colored IR) Precipitation Enhancement

Fig 11 shows the MCIR Precipitation Enhancement applied to the raw image. The MCIR Precipitation Enhancement shows us the accumulation of water in the clouds through various shades of red spots. A dark red spot means a very dense cloud having more amount of water accumulation. From the image it is evident that parts of Kerala, Tamil Nadu and Karnataka is covered by these dense clouds.


Fig 12 shows the Thermal Enhancement along with the heatmap scale. The blue spots on the thermal image shows a cooler/ low temperature over regions of Kerala, Tamil Nadu and Karnataka. From the above shown images, it can be inferred that the chances of rainfall is more in the regions of Kerala, Tamil Nadu and Karnataka when compared to the other parts of India at that moment of time. Let us consider one image received from Meteor-M2 satellite pass shown below, dated 03/04/2020 at 08:55 IST having a maximum elevation of 49.1° heading northbound.


Fig 13: Image received from Meteor-M2 satellite

The image obtained by decoding the LRPT signal from Meteor-M2 satellite looks much more realistic than the imagesreceived from NOAA satellites. But unlike the images received from NOAA satellites, the enhancements such as MCIR, MSA and Thermal Imaging cannot be applied to the images received from Meteor-M2 satellite. The rainfall or temperature is tough to predict unless it is viewed by a weather or a meteorological expert. Factors like cyclone formation (if any) and direction of heading can be inferred from the Meteor-M2 satellite images.

CONCLUSION AND FUTURE SCOPE

A. Conclusion
The objective of this paper to build a cost effective base station for receiving images from weather satellites and making a rough weather predictions through these images is successful.
At first, the work was limited only to get signals from the active NOAA satellites which transmits APT signals, using a simple homebrew V-Dipole Antenna. But then, certain ambiguities were experienced. The antenna had to be faced towards north or south with respect to the direction of satellite pass, also the area coverage and quality of the image received was not up to the mark. To overcome this the QFH Antenna was constructed, which is a circular polarized antenna. The quality and area coverage of the image was better when compared to V-Dipole antenna. Later the work was enhanced by trying to pick up signals from Meteor- M2 satellite which transmits LRPT signal. The signal was successfully received using the same setup and decoded to get much more realistic image than received from NOAA satellites. Through the images received, a rough prediction of weather and rainfall over the location Bangalore, India has been done. These images can serve for greater research purpose to weather experts and weather enthusiasts to monitor the climatic conditions and give accurate weather and rainfall predictions.

B. Future Scope
- The received images can be used for greater research purpose for more accurate weather prediction.
- The same project set up with a suitable antenna can be used to receive signals from geostationary satellite like GOES-16, and the same signal can be decoded to obtain images with a much vast coverage, covering almost half of the earth.
- To record near space images or videos without the help ofsatellites, a high-altitude weather balloon can be manually launched with a payload consisting of a high-resolution camera. Also, few sensors can be interfaced with a microcontroller and put in the payload to measure parameters like pressure, altitude, temperature wind speed etc. in real time. Once the high-altitude weather balloon reaches certain height it explodes causing the payload to be dropped at a random location. With the help of a RF transmitter mounted on the payload, by using the SDR (Software Defined Radio), the payload can be tracked and recovered.
- The same project setup can be used to receive the ADS-B (Automatic Dependent Surveillance- Broadcast) signal transmitted by the aircrafts, and it can be decoded to obtain parameters related to aircrafts such as distance travelled, heading direction, call-sign, speed, altitude, route etc.
- The SDR along with an appropriate antenna can be used to listen to the HAMbands.

REFERENCES

[1] S.Mahmood, M. T. Mushtaq and G. Jaffer, “Cost efficient design approach for receiving the NOAA weather satellites data”, 2016 IEEE Aerospace Conference, Big Sky, MT, 2016.
[2] C. Velasco and C. Tipantuna, “Meteorological picture reception system using software defined radio (SDR)", 2017 IEEE Second Ecuador Technical Chapters Meeting (ETCM), Salinas, 2017.
[3] C. Patil, T. Chavan and M. Chaudhari, "Hardware and software implementation of weather satellite imaging earth station", 2016 International Conference on Advances in Computing, Communications and Informatics (ICACCI), Jaipur, India, 2016.
[4] F. P. A. Escobedo, H. R. Álvarez, H. Salazar, C. G. R. Percing andR.
L. J. M. de Oca, "Low cost optimization method of a double cross antenna satellite reception system for the processing and improvement of meteorological satellite signals and images NOAA 15-18-19", 2019 IEEE 1st Sustainable Cities Latin America Conference (SCLA), Arequipa, Peru, 2019.
[5] Su-Yin Tan, “Meteorological Satellite Systems”, Springer Briefs in Space Development, Springer, 2014
[6] A. Hassini, A. Belbachir, “Hardware and software consideration to use near real time MSG-SEVIRI and NOAA-AVHRR Images”
Programming and Systems Symposium ISPS, 2013, pp 12-16
[7] K. Vachhani, A. Rao, “Experimental study on wide band FM receiver using GNURadio and RTL-SDR”, International Conference on Advances in Computing, Communications and Informatics,ICACCI 2015
[8] N. Crisan y L. Cremene, “NOAA Signal Decoding and Image Processing Using GNU-RADIO” ACTA TECHNICA NAPOCENSIS Electronics and Telecomunicactions, vol. 51, nº 1, pp. 1-5, 2012.
[9] V. Dascal, P. Dolea, O. Cristea y T. Palade, “Advanced VHF Ground Station For NOAA Weather Satellite APT Image Reception” ACTA TECHNICA NAPOCENSIS Electronics and Telecomunicactions, vol. 53, nº 3, pp. 1-7, 2012.
[10] How To Build A QFH (Quadrifilar Helix Antenna) to Download Images From Weather Satellites: http://tinhatranch.com/how-to-build- (http://tinhatranch.com/how-to-build-a-qfh-quadrifilar-helix-antenna-to-download-images-from-weather-satellites/) a-qfh-quadrifilar-helix-antenna-to-downloadimages-from-weather- (http://tinhatranch.com/how-to-build-a-qfh-quadrifilar-helix-antenna-to-download-images-from-weather-satellites/) satellites/#.XqQ14mgzaM8 (http://tinhatranch.com/how-to-build-a-qfh-quadrifilar-helix-antenna-to-download-images-from-weather-satellites/)
[11] DIY 137 MHz WX SAT V-dipole antenna: https://lna4all.blogspot.com/2017/02/diy-137-mhz-wx-sat-v-dipole- antenna.html

[12] RTL-SDR Quick Start Guide: https://www.rtl-sdr.com/rtl-sdr-quick- (https://www.rtl-sdr.com/rtl-sdr-quick-start-guide/) start-guide/ (https://www.rtl-sdr.com/rtl-sdr-quick-start-guide/)
[13] Tutorial for receiving and decoding signal from Meteor-M2 satellite: http://happysat.nl/Setup_Meteor/Setup.html
[14] Zadig: https://zadig.akeo.ie/
[15] SDR#: https://airspy.com/download/
[16] WxToImg: https://wxtoimgrestored.xyz/
[17] LRPT Decoder: https://leshamilton.co.uk/MeteorLRPTSuite.htm
[18] Orbitron- Satellite Tracking System: http://www.stoff.pl/
[19] VB Cable- Virtual Audio Cable: https://www.vb-audio.com/Cable

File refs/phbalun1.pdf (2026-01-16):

# The Paul Hayes Quadrifilar Helix Antenna Trifilar Balun construction for QHA

### Balun design by Bob Thorpe G4UNU


Document layout Angus Anderson ZR6UM

Parts required
1) 5 - 10cm of 22mm outside diameter plastic drain piping. This will be cut down to 18mm
2) OPTIONAL Copper jig made from 3cm of 22mm ID copper tubing, drilled with W1 to W3 holes
3) 35mm plastic film case with a flat top for balun assembly. The flat top makes sealing easier
4) 35mm ridged film case top, for end cap.
5) Plastic spacing washer to go with balun assembly. I use the plastic from the sides of old kitchen unit drawers, I am sure most people have similar bits lying around the shack.
6) 2 way plastic screw terminal block for connecting RG-58
7) Two 2.5 mm * 25mm bolts and four nuts.
8) About 50cm of 18swg enameled copper wire, for balun
9) Superglue or quickset epoxy for securing windings
10) Weatherproof putty for sealing RG-58 exit from film can

Tools Required
1) Pub Dart or sharp pointed awl to make 1mm holes
2) Hand or power drill, with assorted drills 2mm to 10mm
3) Fine sandpaper to clean enamel off copper wire
4) Soldering iron with fine tip and rosin cored solder

## Trifilar Balun: Tool and parts requirements

Notes for those who don’t live in the United Kingdom

Most of the components specified here, such as the film can, enamelled copper wire, and so on, are almost universally available worldwide. You will have to improvise to get those parts that are not available. The only advice I can give is to make any substitutions as close as possible in physical dimensions and electrical specification to the original specified.

However, to realise full balun performance, it’s important to stick to the specified O.D. of the coil former. If you can’t get the right thing, I suggest you make a former out of something like a toilet roll cardboard centre, or similar non-conductive material.

## Trifilar Balun: Construction And mounting

Illustrative references are opposite the text.


Start with a piece of 22mm diameter plastic overflow pipe.
(Can’t you tell I was in the pub darts team?) Because I make quite a few baluns, I made a jig to assist in making the holes in the plastic former. This is a jig that slides over the plastic pipe, and has the holes pre-marked. The plastic former should be 18mm long, but leave it longer for now. Mark in from the edge 5mm then make a hole big enough to take the 18 SWG (1.25mm)wire.


Measure 5mm from the top of the former. Drill or punch a hole to take enamelled copper wire.Then measure 12.5 mm from the same edge and make a hole directly in line with your first hole. This should give you a gap of 7.5mm between holes. The first hole is the start of Winding 1 (W1) and the second hole is the finish of W1. Turn the former 90 degrees anticlockwise. In line with W1 start, make a hole for W2 start, but 90 degrees offset. In line with W1 finish, make a hole for W2 finish, but 90 degrees offset. Do the same with W3, but turning another 90 degrees anticlockwise from W2
See the drawings at right

Measure 18mm from the top of the former, and cut the former to 18mm long. You should now have three pairs of holes, offset by 90 degrees from each other. Starting from the top left hole, feed some wire through the hole leaving about 25mm protruding out through the tube, then start wrapping the wire anticlockwise around the former. Wind the wire 360 degrees then go another full turn (720 degrees or 2 turns total) so that the winding finishes at the hole
opposite the one you started from. Cut the wire so
that after you have fed the wire through the former


you have about 25mm of wire sticking through. | Terminal


Winding anticlockwise, feed another piece of wire through W2 start, and wind it 720 degrees (2 turns) ending at W2 finish. W2 wire is closely interleaved with W1.


Feed a final piece of wire through W3 start, interleave with W1 and W2, and end at W3 finish. The start and finish ends exit opposite ends of the former. You now have three start wires coming out of one end, and three finish wires coming out the other end. Scrape off all the enamel from the ends that come through the former.


This bit gets a little confusing but here goes!

W2 start is now bent down through the inside of the former and twisted around W1 finish.

W2 finish is bent up through former and twisted around W3 start.

Looking at the former so that W1 start is at the top, W3 start should have W2 finish attached and W1 finish should have W2 start attached.

Ensure both ends of W2 are the same length.

Solder the joints between W3 start-W2 finish & W1 finish-W2 start.

Now double check and if it’s wrong don’t blame me ;-)


Shape W1 start and W3 start wires as shown, and tin the scraped ends. Form the ends into a circle to accept the head of a threaded bolt (6BA or similar). Fit the bolts.


Scrape and tin the ends of W1 finish and W3 finish and fit a screw connecting block as illustrated. Note that the RG-58 braided screen goes to W1 finish.

Drill the 35mm canister top to clear the bolts (about 22mm centres). Fit the 35mm canister top, then seal the coils with superglue. Note: make sure your windings are close together (a tip from Bob Thorpe) abefore glueing. You can also wrap some self amalgamating tape around windings.


Drill the Plastic spacer as shown with holes on about 22mm centres. Check spacing with the bolts in place Fit the plastic spacer.


Drill the bottom of the film canister to clear the RG-58 cable, Prepare the RG-58 and connect to the terminal block, making sure that W1 finish goes to the RG-58 screen. Finally, fit the bottom of the film canister to the top and seal the RG-58 exit hole with weatherproof putty.


All you need to do now is fit the balun to your QFH. Remember when connecting your coax to fit the coax centre core to the right hand connecting terminal

### Please let me know if you see anything

wrong. Any comments to Paul Hayes please.

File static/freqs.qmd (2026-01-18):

---
title: Allocated requency bands
format: html
---

These are some notes on allocated frequency bands that may be helpful. Amateur radio band can be found at the [ARRL site](http://www.arrl.org/frequency-allocations). These are focused on US allocations. 

## LoRa 

### APRS

for APRS over LoRa there's not well-defined frequencies. 

- UHF - 433.775
- 33mm -
  - APRS: 916.5 MHz 
  
### Meshtastic 

- [LongFast: 906.875 MHz](https://meshtastic.org/docs/overview/radio-settings/)

## GPS

- L1: 1575.42 MHz
- L2: 1227.60 MHz
- L5: 1176 MHz

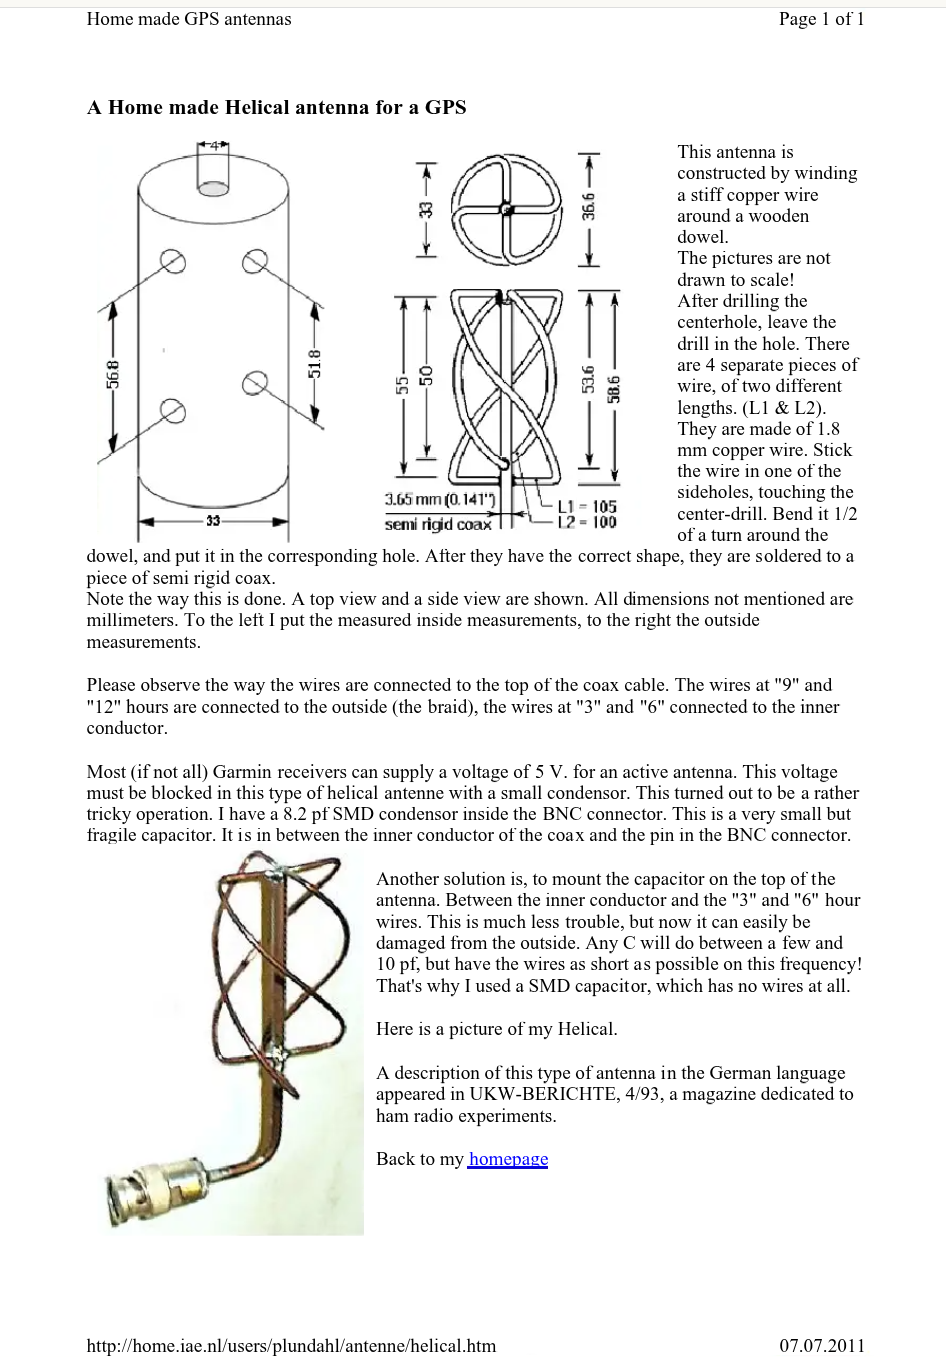
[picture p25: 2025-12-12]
refs/2025-12-12-helical-capture.png

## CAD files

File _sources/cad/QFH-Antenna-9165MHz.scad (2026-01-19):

// OpenSCAD script for a 916.5 MHz band QFH antenna.
// Modified from git@github.com:cernohorsky/QFH-Antenna-868MHz.git
// I'm using a 12 AWG wire, approximate 2.0 mm diameter.
// plan is to use this as a form for winding and then build the antenna
// without the PLA form to avoid the dielectric loading effects.
// - KF8EEZ



// These are the original comments from  git@github.com:cernohorsky/QFH-Antenna-868MHz.git
// OpenSCAD script for a 868 MHz ISM band "quadrifilar helix antenna".
// The design originated in: http://www.thingiverse.com/thing:634205
// -------------------------------------------------------------
// Dimensions calculated with John Coppens webpage java script
// @ http://jcoppens.com/ant/qfh/calc.en.php
// Input params:
// Center frequency = 913 MHz
// Numbers of turns = 0.5
// Length of one turn = 1
// Bending radius = 1.5 mm
// Conductor diameter = 0.8 mm
// Width/height ratio = 0.44
// 
// -------------------------------------------------------------


$fn=80;

PI = 3.14159265358979;

D1 = 45.6; // mm large helix1 diameter. Di1
D2 = 43.3; // mm small helix2 diameter. Di2
HH1 = 108.4; // mm height of helix1.
HH2 = 103.0; // mm height of helix2.

WIRE = 2; // mm diameter.

CYLH = 120; // mm height of support cylinder.
CYLH2 = CYLH/2; // the half-height of the support cylinder.
SLICES = 60;

HWIRE11 = CYLH2-HH1/2; // place the four hole-pairs at these heights.
HWIRE12 = CYLH2-HH2/2;
HWIRE21 = CYLH2+HH1/2;
HWIRE22 = CYLH2+HH2/2;

EXTRUSION_WIDTH=0.6; // original value
//EXTRUSION_WIDTH=3.0; // this is the wall of the support cylinder

pedestal_height = 1;   // designed for use the MLAB standard 12mm screws.
mount_hole = 3.5;
clear = 0.175;

MLAB_grid_xoffset = 4.2;
MLAB_grid_yoffset = 4.2;
MLAB_grid = 10.16;


// some internal calculations. quite hairy math.
THETA1 = atan2(HH1,D1*PI); // Thetas are used for projecting the wirechannel cross-section onto the xy-plane.
THETA2 = atan2(HH2,D2*PI);
echo("theta1=",THETA1,"  -  theta2=",THETA2);

XSI1 = ((CYLH/HH1*180)-180); // extra rotation beyond the height of helix1. half above, half below.
XSI2 = ((CYLH/HH2*180)-180); // extra rotation beyond the height of helix2.
echo("xsi1=",XSI1," - xsi2=",XSI2);



//------------ Safety grid parameters---------------------------

nY = 5;
nX = 5;


meshX=100;
meshY=100;

// width of solid part of grid
meshSolid=1.2;

meshSpaceX = (meshX - meshSolid*nX)/nX;
meshSpaceY = (meshY - meshSolid*nY)/nY;




module base(){
    union()
    {
        for (i=[1:nX-1]) {
                 translate([i*(meshSolid+meshSpaceX) - meshSolid/2,0,0]) cube(size=[meshSolid, meshY, pedestal_height],center=false);
        }

        for (i=[1:nY-1]) {
                translate([0,i*(meshSolid+meshSpaceY) - meshSolid/2,0]) cube(size=[meshX, meshSolid, pedestal_height],center=false);

        }
    }
}


// test helix1.
module helix1(rot1=0)
{
	linear_extrude(height=50, twist=-XSI1-180, slices=SLICES) 
		rotate([0,0,rot1-XSI1/2]) translate([D1,0,0]) projection() scale([1,1/sin(THETA1),1]) wirechannel();
}

// test helix2.
module helix2(rot2=90)
{
	color("red") linear_extrude(height=50, twist=-XSI2-180, slices=SLICES) 
		rotate([0,0,rot2-XSI2/2]) translate([D2,0,0]) projection() scale([1,1/sin(THETA2),1]) wirechannel();
}



// definition of the wire channel by CSG. 
// used for projecting outline onto the xy-plane.
module wirechannel()
{
	difference()
	{
		cylinder(h=2, r=WIRE*0.8, center=true);

		translate([0,0,-0.1]) 
            cylinder(h=3, r=WIRE/2, center=true);

		translate([1.5*WIRE,0,0]) 
            cube([3*WIRE,WIRE,4], center=true);
	}
}

// definition of elliptic cylinder by CSG.
// used for projecting outline onto xy-plane.
module ellipse_base()
{
	scale([1,D2/D1,1]) 
        difference(){ 
            cylinder(h=1, r=(D1/2-WIRE/2), center = true); 
            cylinder(h=2, r=(D1/2 - WIRE/2 - EXTRUSION_WIDTH), center = true); 
        }
}

// just a elliptic torus.
// (penalty for using $fn quality.)
module torus(Rmajor=10, Rminor=1, h1=25)
{
	translate([0,0,h1]) scale([1,D2/D1,1]) rotate_extrude(convexity = 10) translate([Rmajor, 0, 0]) circle(r = Rminor); 
}

// the composite structure of support cylinder, wire channels, holes and cut-outs.
module composite()
{
	difference()
	{
		union()
		{
			// combine all elements in one extrude and twist.
			// helix1's.
			linear_extrude(height=HWIRE21, twist=-XSI1/2-180, slices=SLICES)
			{
				rotate([0,0,0-XSI1/2]) translate([D1/2,0,0]) projection() scale([1,1/sin(THETA1),1]) wirechannel();
				rotate([0,0,180-XSI1/2]) translate([D1/2,0,0]) projection() scale([1,1/sin(THETA1),1]) wirechannel();
			}
			// helix2's.
			linear_extrude(height=HWIRE22, twist=-XSI2/2-180, slices=SLICES)
			{
				rotate([0,0,90-XSI2/2]) translate([D2/2,0,0]) projection() scale([1,1/sin(THETA2),1]) wirechannel();
				rotate([0,0,270-XSI2/2]) translate([D2/2,0,0]) projection() scale([1,1/sin(THETA2),1]) wirechannel();
			}
			// elliptic support cylinder.
			linear_extrude(height=CYLH, twist=-XSI1/2-180, slices=SLICES)
			{
				rotate([0,0,0-XSI1/2]) projection(cut=true) ellipse_base();
			}

			// half-height marker on cylinder
			//rotate([0,0,90]) torus(Rmajor=(D1/2-WIRE/2), Rminor=0.2, h1=CYLH2);
		}
		union()
		{
			// lower hole pairs.
			translate([0,0,HWIRE11]) rotate([0,90,0]) cylinder(h=3*HH1, r=WIRE/2, center=true);
			translate([0,0,HWIRE12]) rotate([90,0,0]) cylinder(h=3*HH1, r=WIRE/2, center=true);

			// upper hole slots.
			translate([0,0,HWIRE21]) rotate([0,90,0]) cylinder(h=3*HH1, r=WIRE/2, center=true);
			translate([0,0,HWIRE22]) rotate([90,0,0]) cylinder(h=3*HH1, r=WIRE/2, center=true);

			translate([0,0,HWIRE21+CYLH2]) cube([CYLH,WIRE,CYLH], center=true);
			translate([0,0,HWIRE22+CYLH2]) cube([WIRE,CYLH,CYLH], center=true);
		}
	}
	//translate([-50,-50,0])
	//	base();
}

module drillholes()
{
	// lower hole pairs.
	translate([0,0,HWIRE11]) rotate([0,90,0]) cylinder(h=3*HH1, r=WIRE/3, center=true);
	translate([0,0,HWIRE12]) rotate([90,0,0]) cylinder(h=3*HH1, r=WIRE/3, center=true);

	// upper hole pairs.
	translate([0,0,HWIRE21]) rotate([0,90,0]) cylinder(h=3*HH1, r=WIRE/3, center=true);
	translate([0,0,HWIRE22]) rotate([90,0,0]) cylinder(h=3*HH1, r=WIRE/3, center=true);
}

//wirechannel();
//helix1(rot1=0);
//helix1(rot1=180);
//helix2(rot2=90);
//helix2(rot2=270);
//drillholes();
//ellipse_base();
//base();

// MAIN()
composite();

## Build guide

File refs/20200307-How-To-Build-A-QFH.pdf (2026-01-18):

## How To Build A QFH (Quadrifilar Helix Antenna) to Download Images From Weather Satellites

### Used with Permission-from the web site Tin Hat Ranch - http://tinhatranch.com/

NOTE: I turned his page into a PDF, and I added some links, and some suggestions/clarifications that I used in my antenna build. Additions are in RED by me, Carl Reinemann http://radiolab.dodgem37.com

Every few hours a NOAA weather satellite passes over your head, continuously transmitting pictures in visible light, infrared, and shortwave infrared. Meteorologists utilize this information to predict weather. The good news is, so can you. With something like the NooElec SDR dongle, a computer, and a QHF antenna you can predict your own weather, even if all other forms of communication are not functioning. The “bad news” is, you have to build an antenna to receive the data. It’s not really bad news, but you will have to make an investment of both time and a little bit of money to start downloading your own images.
Why do I need to build such a complex looking piece of machinery? That’s a good question; the answer is the Government doesn’t want you to have access to this data. No, seriously, it has to do with simple physics and the nature of radio. Here is a simple explanation- Antennas perform best when they are properly polarized, or the antennas are pointed in the same direction in three dimensional space. If you were to take two walkie talkies and point one antenna straight up and one sideways at a 90 degree angle you would notice that the reception would be severely degraded or nonexistent, even if in the same room. When you have a satellite orbiting the earth, even if the antenna is pointed straight down, its polarization to you on earth will change as it goes from horizon to horizon. The solution is to build an antenna that is properly polarized in all directions, hence the QFH antenna.
What do I need to build the QHF antenna? There are many ways to build this antenna and many tutorials can be found when scouring the web. I did NOT design this antenna myself and after looking at tons of them myself I settled on the antenna above for a few reasons. It is a design by Bill Sykes G2HCG and Bob Cobey G0HPO and I used their tutorial that can be found here in constructing mine. My intentions with this “how to” is for you to utilize their page for exact dimensions and my construction notes to make it easier to build. They tell you what is needed for the antenna, but are a little short
on how to put it together. The reason I chose this antenna was its rugged design, performance, and when you are done, it looks like a work of art. To build this antenna you will need to be mechanically inclined and willing to dedicate a weekend to the project. If you have none of the materials on hand it is going to run you a bit over $100 (Mine was about $35 for total build, but I had some stuff in my shop) to procure everything. Most of the materials can be purchased from any home improvement store, but here is the shopping list-Tools and Consumables
(1) 10ft. length 1 1/4″ Schedule 40 PVC pipe- You won’t need the entire length so if your store sells 5ft pieces that would be OK as well
(1) 1 1/4″ PVC End Cap
(1) Can Each PVC Cement and Primer
(1) Coil of 3/8″ OD Copper Tubing, 25ft. in length,
(1) Tubing cutter
(8) 90 degree end fed 3/8″ Copper elbows. These were hard to find in the local HI store, Lowes had them, but you can get them online here. Make SURE they are for 3/8″ OD tubing..sometimes they are called 1/4″ elbows. I bought mine at our local Menards store, about .80 cents each
(1) Roll of Pipe Solder I also used solder flux as well.
(1) Roll of Electrical Tape
(1) 10ft RG-58 Jumper – Its cheaper just to buy a jumper than a whole roll. You will be cutting off one end. I Used RG-6 Cable, Worked great
(4) 18ga Ring Terminals– Size doesn’t really matter here.
(1) 2 ft. piece of 18 Gauge Wire
(1) Tube of outdoor clear silicon sealant.
(1) Tape metric tape measure or some maff skills and a ‘Merica version
(1) Drill and 3/8th” Drill bit
(1) Larger cardboard box, piece of cardboard or wood ~25″x12″ (600mm x 305mm)
(1) SO-239 Connector I used RG-6 connectors with RG-6 Cable
(4) #8 1/2″ Sheet Metal Screws
(1) 3ft 1″x4″ to be used as a straight edge

Optional: Rustoleum Plastic Paint, 1/ ¼ “ PVC threaded connectors, male and female
Building The Antenna
Please note you can click on all photos to be shown full size.
Remember, I built my antenna using this design and using this tutorial. It is a great design and reference, but it completely lacks a “how to” feel. My intention is to tell you HOW I did it.

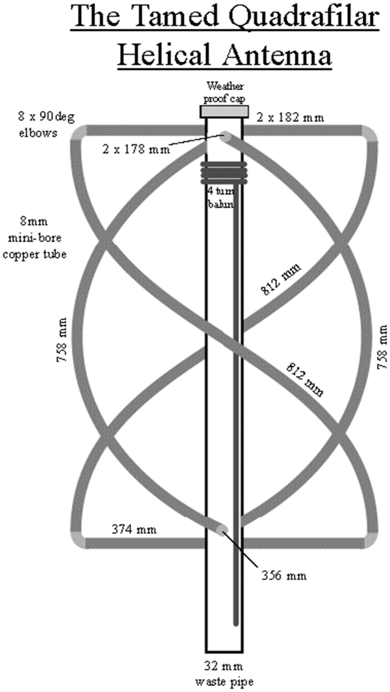
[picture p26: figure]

The very first thing you are going to have to do is prepare the PVC section of pipe. The actual antenna portion of the pipe is going to be 560mm (22″) tall, but you will need to put a cap on the top of the pipe and also have some tubing protruding below the antenna portion for mounting. I arbitrarily picked 3 feet for total size.

For the top of the antenna you are going to have to drill (4) holes at right angles to one another. This will require you to make two templates, one for the top of the pipe and one for the bottom.
Your templates should look something like this.

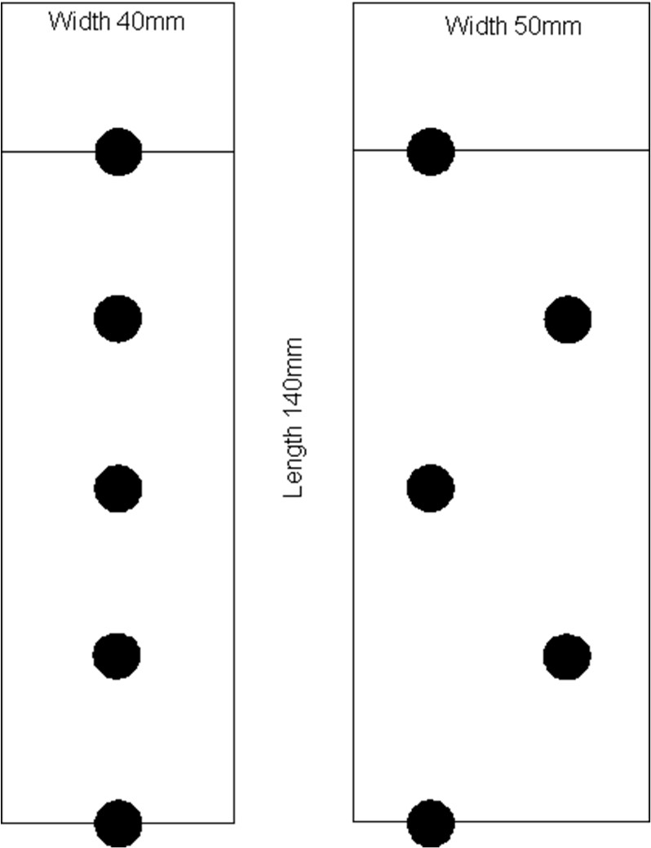
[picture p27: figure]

I took a sheet of paper and cut out a 40mm wide strip. Draw a line down the middle of the paper. This will put your drill points 20mm from the top of the pipe. This is important because you will need room for the cap, but you DO NOT want to have to wire something way down inside the pipe. Take your 40mm wide paper strip and wrap around the pipe, marking the point where it overlaps. Take the paper off the pipe and measure the mark you made where it overlapped, this is the
pipe’s circumference. Take that number and divide by 4. The point where the papers meet will be one mark, then take your measurement and mark the other three drill points. I am not providing these measurements as I do not know if all PVC OD is standard.

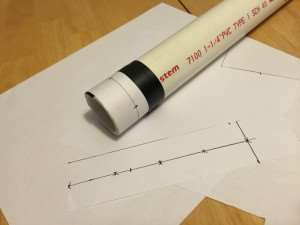
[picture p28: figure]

Next you will do almost the same again, this time you will cut a 50mm wide strip of paper. Make two parallel lines on the paper exactly 24mm apart. Take your measurement (Circumference divided by 4) and mark your drill points on the paper, this time staggering the points between the two lines.

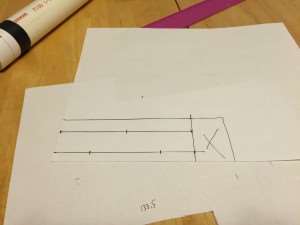
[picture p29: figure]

Next, you will have to tape these templates to the pipe where the holes must be drilled. This must be done as close to exact as possible and so the antenna elements are all 90 degrees apart from one another.
To give you a picture of what the finished result should be Using electrical tape, wrap the first piece of paper at the top of the pipe and secure it. Then take the second piece of paper and measure exactly 560mm from the top line to the bottom line of the second piece of paper. These holes must line up. I took a piece of straight 1″x4″ and used it to line up the markings for the holes.
Once everything is lined up, use your 3/8″ drill bit and drill the holes. If you have a drill press..even better.

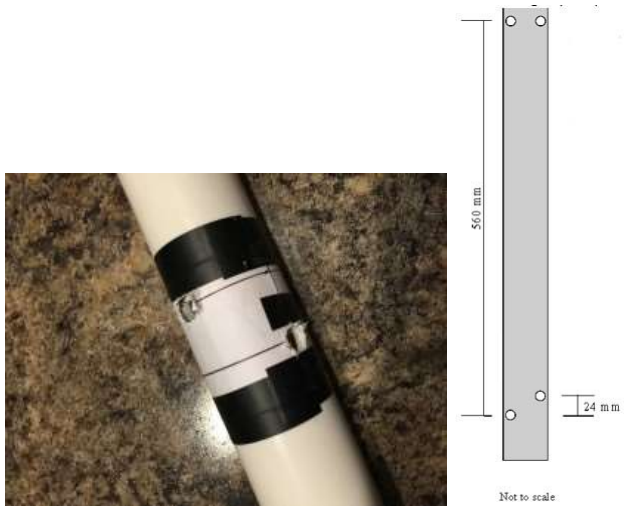
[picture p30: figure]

Lastly, you will need to drill holes for the coax balun. This can be done anywhere on the pipe, but I did it about 6 inches below the top holes. I put my coax balun 1 inch below top antenna elements. Take your coax and wrap it around the pipe so the end result will be 4 complete turns and mark where the coax will go through. After this step you might want to consider painting the PVC pipe. I will generally use a fine sandpaper then spray paint it with.

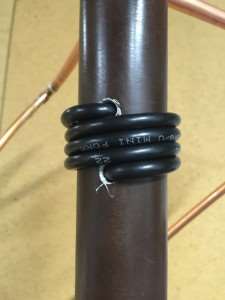
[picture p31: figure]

The antenna is made up of (10) separate pieces of copper..let the fun begin. You will need pieces in the following lengths-
(2) 812mm
(2) 758mm
(1) 374mm
(1) 356mm
(2) 182mm
(2) 178mm
Basically, you have to turn this-

Into a bunch of straight pieces. Here is what I did. When working on the 812mm pieces, I would cut it maybe 10-20mm too long. I would carefully bend it as close as possible to the 1″x4″. Then I would roll it like dough until it was nearly perfect. Some local home improvement stores will have short pieces of 3/8″ copper tubing. If they have it, spending a few extra bucks will save you a ton of time for all but the longest pieces.
Once your pieces are straight you will need to cut them to the closest millimeter. One trick I came up with when cutting the pieces to length was to use a piece of electrical tape to mark the exact point that needed to be cut. Measure your piece and place a piece of tape right where your tubing cutter needs to go. Then loosely fit your tubing cutter over the tubing and slide it up until it hits the tape, tighten it down, and start cutting.

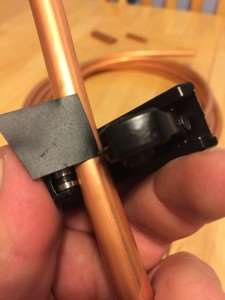
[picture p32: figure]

Once you have all of your pieces straightened out and cut you will have to then re-bend the longer pieces into a half circle. I took a piece of cardboard, string, and two pencils and made a rudimentary compass. I first took the radius of the 812mm piece and scribed out a half circle on the cardboard. You can go the extra mile and do this in wood as well, but the cardboard worked just fine for me.

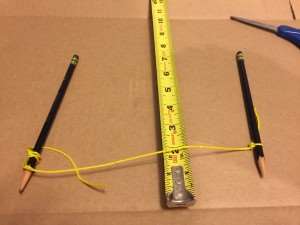
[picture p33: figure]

Once I had the line scribed I cut out the cardboard.

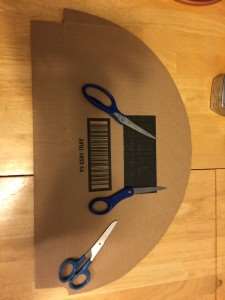
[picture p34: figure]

Make sure you use a sturdy pair of scissors.
Then carefully bend the tubing around the cardboard template.

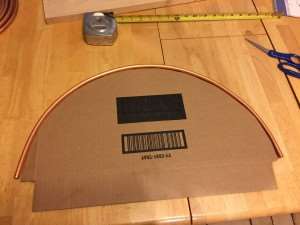
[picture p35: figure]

When you have the 812mm pieces done, you can re-measure and cut for the 758mm pieces and repeat the process.

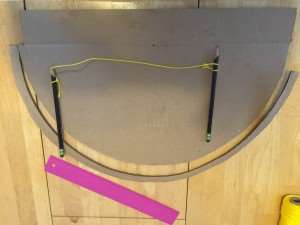
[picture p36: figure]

Once all of your long pieces are shaped, you can begin assembling the antenna. At this point it begins to be putting pieces of the puzzle together with one exception. You must bend the long pieces on their perpendicular axis. This can be a bit tricky, so here is how I did it.
First, note that the top of the antenna receives the 178mm and 182mm straight pieces. Both 178mm pieces are opposite of one another and both 182mm pieces are opposite. At the bottom of the antenna, the lower holes get the 374mm piece and the holes that are 24mm above get the 356mm piece. The 182mm and 374mm pieces are parallel to one another. The 178mm and 356mm pieces are parallel to one another. Assemble them in their respective holes.
Once the straight pieces are in, take an 812mm piece and lose fit a 90 degree elbow on each
end. Attach one to the top cross bar like in the picture below.

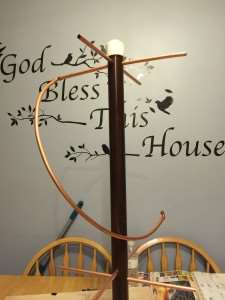
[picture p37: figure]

Grasp the top connection with one hand and gently bend the 812mm piece to meet the lower cross bar on the opposite size. You must bend the ENTIRE antenna ANTI-CLOCKWISE when viewed from the top. I repeat, you must bend each leg ANTI-CLOCKWISE. The bend should be as even as possible, and I frankly don’t have any magic way to get this done or confirm it was done correctly other than the old hairy eyeball.

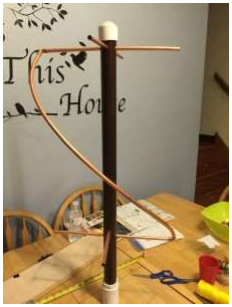
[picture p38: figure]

Then repeat with the other 812mm piece. If something looks out of place and not even, just do your best to shape it to the best of your ability.
Then move on to the short leg with the same procedure.
Once all four legs are on and you are sufficiently satisfied that they are as even as possible your antenna should look something like this-

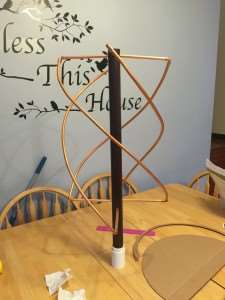
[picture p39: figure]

Again, once you are satisfied, it is time to “lock it down” by sweating the tubing and elbows together. NOTE: clean the ends of the tubes, and the inside of the joints, apply pipe flux inside and out. It doesn’t take much heat time with the torch at all, the solder will flow in. Really simple

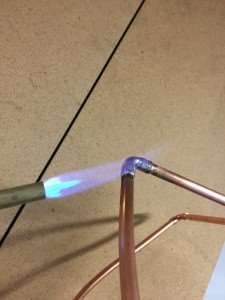
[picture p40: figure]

If you are still with us, good news, most of the hard stuff is over. The next step is getting the coax in and making the balun. In my case, I took my coax jumper and cut both ends off. Take about four feet and stuff it through the bottom hole you drilled earlier. Then wrap it around so you have four complete turns. Cut the other end so that a foot or so will be left when you stuff it through the upper hole. Then stuff it through the upper hole. If you do this correctly, the tension in the coax will hold it just fine. NOTE: I placed mine just 1 ½” inches below top copper elements. Also, I fed coax into the top hole and up to the connection site, then made the soldered connections. This was easier and allowed me to pull any slack out of coax, then I did the four turns, passing into the bottom hole and out the bottom. I sealed mine with Silicone and wrapped the balun in electrical tape as well.

Now we will have to make two jumper wires to connect the two legs of the antenna. Take a piece of wire, I think I used 18ga here, it doesn’t really matter. Cut it as small as you are comfortable working with and crimp or solder ring terminals on the ends. Then strip a bit of the wire in the center.

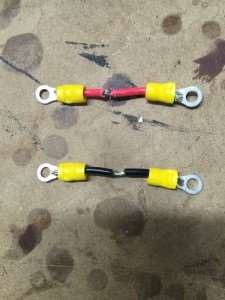
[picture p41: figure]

Did I say the tough part was over? I meant almost. I wish I would have taken a picture of this, but I didn’t. You are going to have to drill a tiny guide hole in each of the four pieces of tubing, inside of the pipe. Then using the small sheet metal screws, you are going to have to screw down the ring terminals to the tubing. I had to bend the terminals up to a 90 degree angle to get them all to fit. You will be connecting one long leg to one short leg for each wire. Again, one long leg to one short leg.

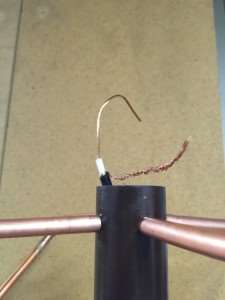
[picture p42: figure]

Then strip the piece of coax so that you have a few inches of extra center conductor and shield like in the picture above. Wrap the center conductor around one of the wires you stripped earlier and solder it, then wrap it in tape. I placed a piece of rigid foam on the inside so that the copper pieces won’t touch and subsequently short out the antenna after final assembly. When this step is finished, your mess should look something like this:

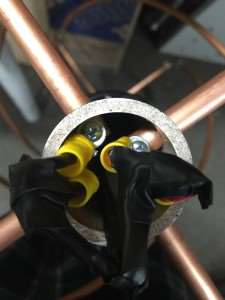
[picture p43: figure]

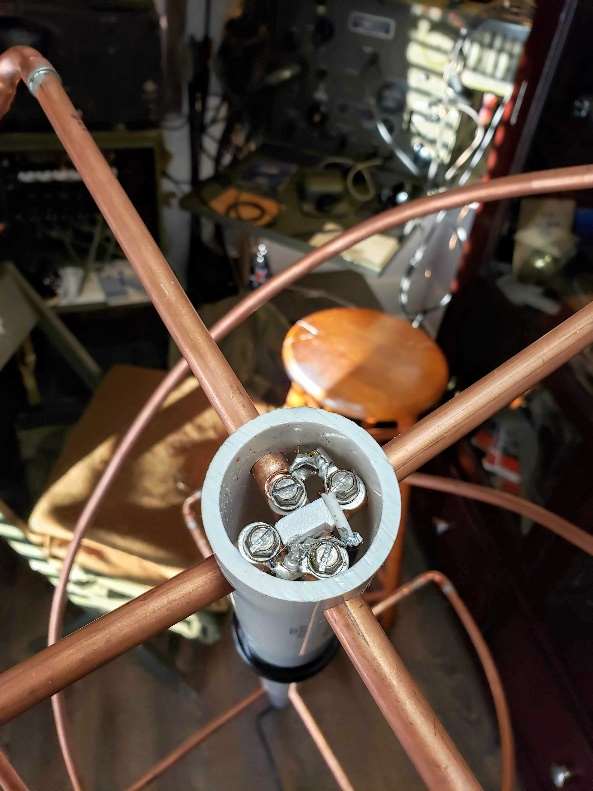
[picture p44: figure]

NOTE: I did mine a bit differently and soldered the connections together in the tube

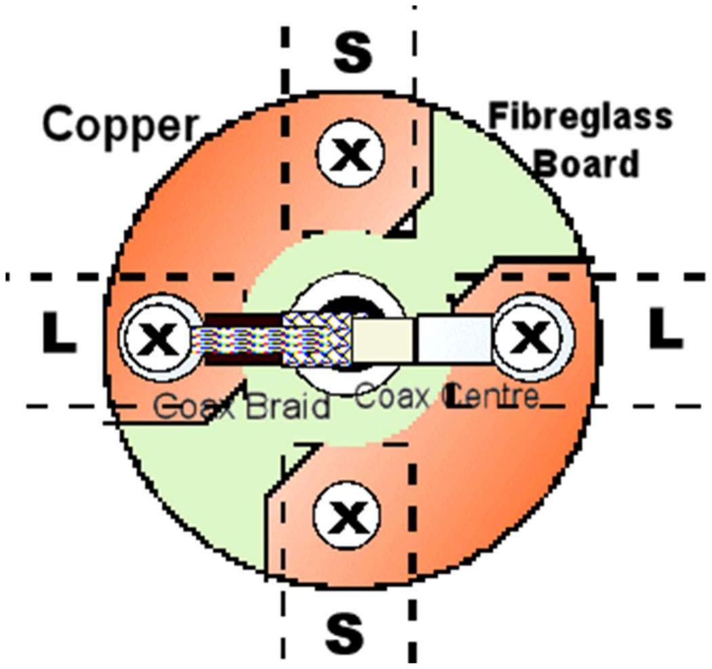
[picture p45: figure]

NOTE, a different way to make Connection, BUT it does show proper wiring a bit clearer. Showing Long and Short element connections. Next, glue on your top cap. Then proceed to use the outdoor silicone to seal every penetration in the pipe. NOTE: I did NOT glue my cap on, I wrapped a single layer of electrical tape around the top of PVC Pipe, then Pressed the PVC Cap on, This way I could easily remove the cap and cek the wiring if theres and issue, or If I want to change the coax.

NOTE: this part may depend or your particular cable, on mine I used RG-6 Quad Shield coax, and just fed it out the bottom so I could run it to a waterproof box that houses my LNA.
The last step in finishing this antenna is one for which I don’t have a good solution. At this point you will have a piece of coax hanging out the bottom of your antenna. You will need to somehow mount a SO-239 chassis connector at the bottom of the pipe. I took a 3/4″ PVC plug, drilled a hole, soldered the coax on to the S0-239, and mounted the SO-239 connector to the plug. The problem is, there is no mechanical way to connect the plug into the bottom of the pipe. I wrapped electrical tape around the plug, then stuffed it into a 1″ coupling. I then took the 1″ coupling, wrapped more tape around it and stuffed it into the bottom of the antenna.

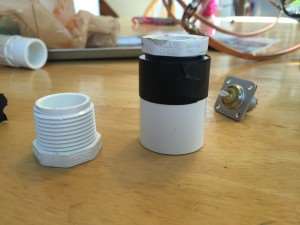
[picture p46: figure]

My antenna has been up for over a year now, and this solution worked. It appears as if there are no leaks and it still functions properly. Mounting this antenna is another animal that will be left up to your situation. I ended up taking a 1 1/4″ to 1 1/2″ coupling and mounted the antenna on top of a piece of 10ft, 1 1/2″ pipe.
I used this to mount mine, UPC # 9434600030 cost about $10 made by RCA and fits a PVC threaded coupler perfectly.

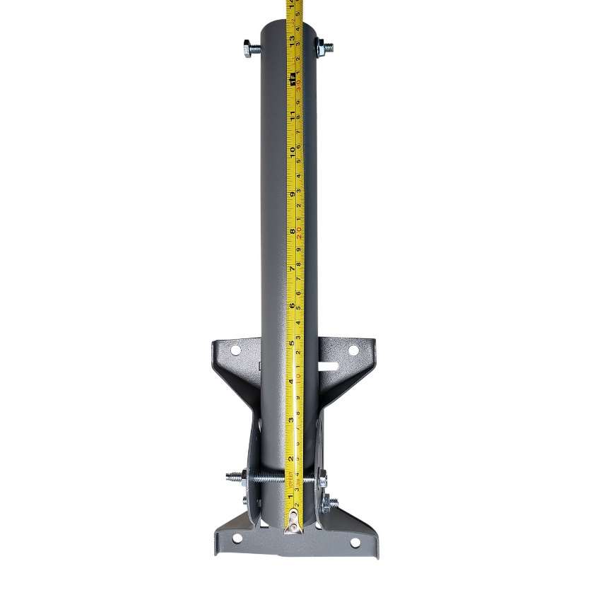
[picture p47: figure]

NOTE: On my antenna, I used a 1/14” male and female threaded coupler on the base, with the RG-6 Quad shield just coming out of the end, so I could run it to a waterproof electrical box to house my LNA

I tested mine with a NanoVNA and it came out at 137.5150 Mhz, centered great on NOAA birds and Meteor at the low end at 137.1, and higher birds at 137.9
This project will take some effort, no doubt, but the end result is something to be proud of..and can help predict weather.

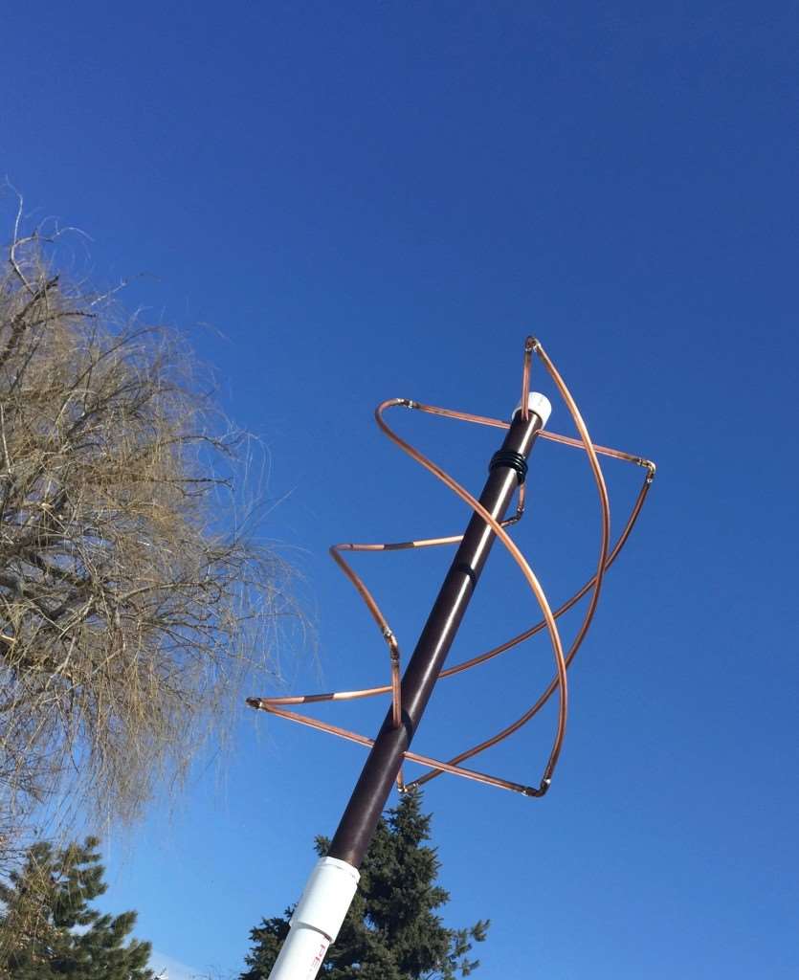
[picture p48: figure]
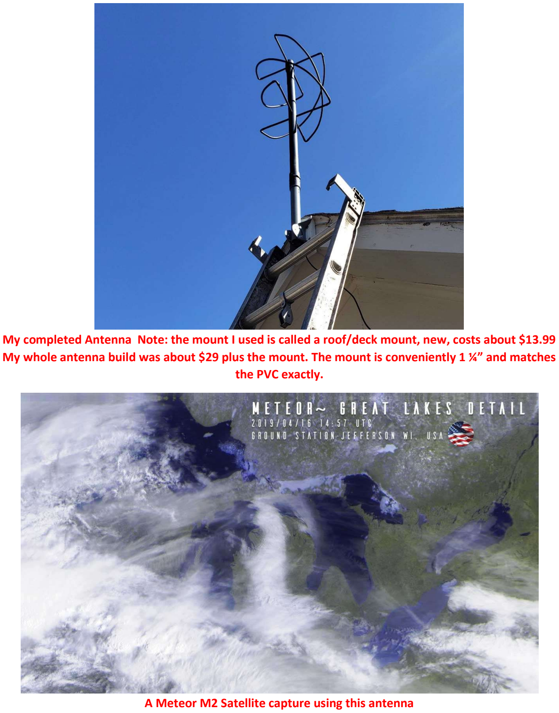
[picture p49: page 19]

My completed Antenna Note: the mount I used is called a roof/deck mount, new, costs about $13.99 My whole antenna build was about $29 plus the mount. The mount is conveniently 1 ¼” and matches the PVC exactly.

A Meteor M2 Satellite capture using this antenna

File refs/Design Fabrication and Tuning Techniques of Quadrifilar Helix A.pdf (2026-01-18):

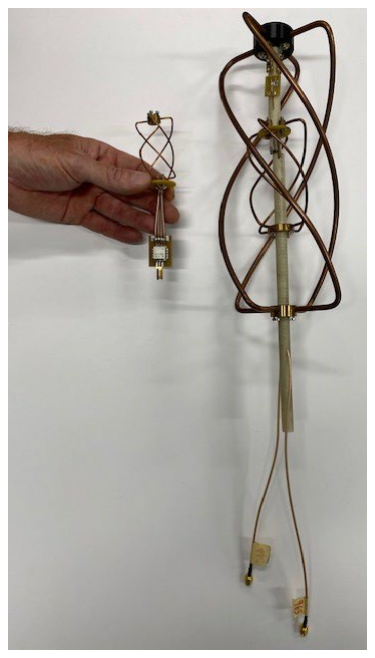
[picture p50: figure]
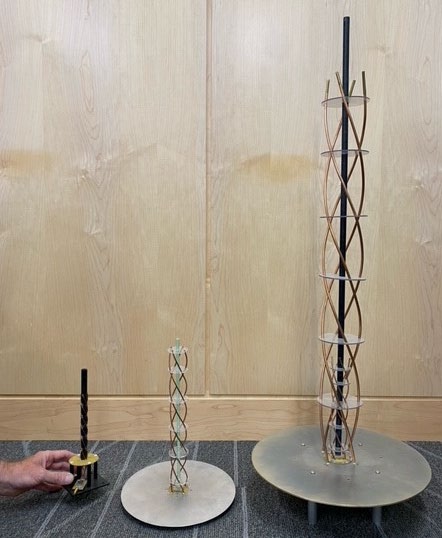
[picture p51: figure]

[Davis] | 1 | 36th Annual Small Satellite Conference

## [SSC22-XII-07]

### Design, Fabrication, and Tuning Techniques of Quadrifilar Helix Antennas for Small Satellites

Kelby Davis
Space Dynamics Lab, Retired. kdinutah@gmail.com
Reyhan Baktur
Utah State University
4120 Old Main Hill, Logan UT 84321; 435-213-0144 Reyhan.baktur@usu.edu

ABSTRACT
Quadrifilar helix antennas are also called fractional turn helix is very appealing to spacecraft applications. A quadrifilar antenna offers circular polarization in its radiating hemisphere and its radiation pattern is not severely affected by a ground plane. These properties are important for closing the communication link and make the antenna relatively independent of the CubeSat frame and mounting location, which facilitates modular design of the antenna. Although it has similar shape as a helical antenna, a quadrifilar helix antenna is fundamentally different. While there exists design theory and calculators for this type of antennas, detailed notes on design, fabrication, and tuning of different geometries of quadrifilar helix antennas are beneficial for small satellite community. This paper presents design data of several successful demonstrations of quadrifilar helix antennas with different geometries and operation bands.
I. INTRODUCTION
A quadrifilar helix antenna (QHA), also called
fractional turn helix, is very attractive for small satellite (SmallSat) applications. A QHA offers appealing properties such as circular polarization (CP) in the entire radiating hemisphere, wide beam-width, relatively independent of a ground plane. All of these are important for SmallSat applications— on the aircraft, or as ground station.
Figure 1 shows several QHAs fabricated by the author. Although it resembles helical antennas, a QHA is a fundamentally different type of radiator. Unlike a traveling wave helical antenna, a QHA is a resonanttype antenna and therefore has a limited bandwidth. It also may not need a ground plane as required by helical antennas. Although there exists a large volume of literature on the subject, this paper sticks to the design principles from the original QHA development by Kilgus [1]-[4] and derives terms and design procedure from notes in satellite community [5], [6].
II. TERMINOLOGY
Since the design procedure and terminology of QHA are radically different from other antennas, including helical antennas, it is important to explain the basic nomenclature. QHAs are also called fractional turn helix, which indicates that we will be using terms such as “half-turn”, “1/2 turn”, or “1/4 turn”. The names “turns” and “element” are defined as follows [5].
(a) (b)
Figure 1: Examples of QHAs
A. Half-turn λ/2 Bifilar Helix
One way of visualizing the half-turn λ/2 bifilar helix, where λ is the wavelength, is to develop it from a continuous quasi-square loop as shown in Figure 2. One could form a loop antenna by feeding this quasi-square

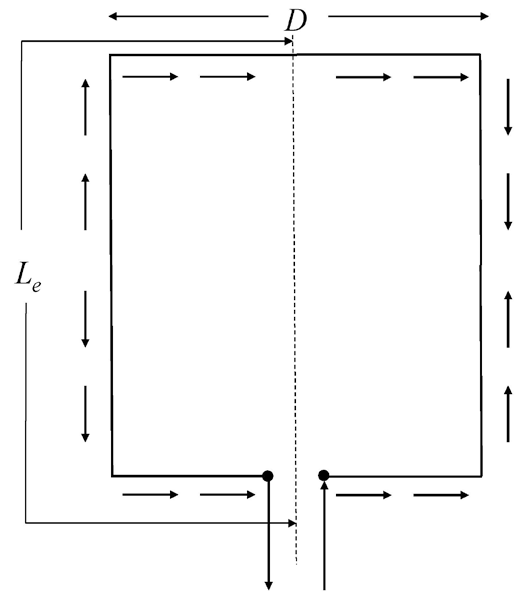
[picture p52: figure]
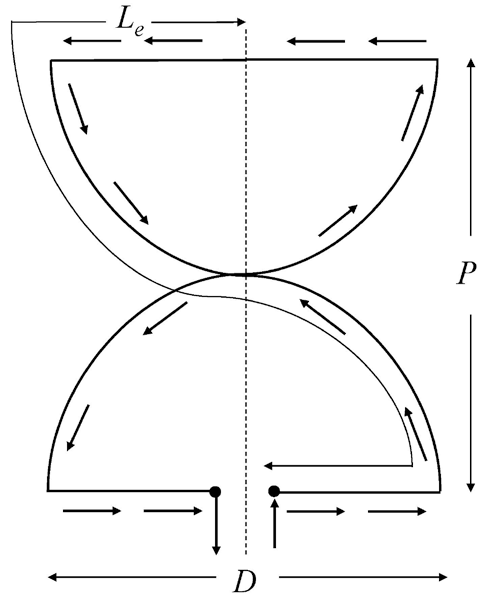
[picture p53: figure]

[Davis] | 2 | 36th Annual Small Satellite Conference

loop from the two open terminals at the bottom. The current distribution (only the direction) of a loop of one λ in circumference is indicated by the small arrows in Figure 2-a.
To form a bifilar, imagine inserting a cylinder of diameter D inside the loop. Then, while holding the bottom side of the loop fixed, grasp the top side and give it a half turn (180◦) rotation with the center line (dash line in Figure 2-a) as axis, with respect to the bottom side. As a result of the rotation, each of the two vertical sides of the quasi-square loop becomes a half-turn helix (Figure 2-b) as it curves around the surface of the imaginary cylinder. Because of the curved paths of the once-straight vertical sides, the distance between the top and the bottom is reduced. This distance is called pitch and marked as P in Figure 2-b.
(a) A Square Loop Antenna
(b) A 1/2 Bifilar
Figure 2: Forming of a 1/2 Bifilar Helix from a Square Loop

The term element length is defined as the half of the loop and marked as Le in Figure 2. The helical structure in Figure 2-b is called a bifilar. The name could be understood as being formed by two elements (defined by Le, D, and P) shorted together on the top and fed from the terminals at the bottom. Following this naming and forming method, a 1/4 turn λ/2 bifilar is a helix formed by rotating two elements of λ/2 by a quarter turn (90◦

), a 1/2 turn λ/4 bifilar is a helix formed by rotating two elements of λ/4 by a half turn, and a 1.5 turn 1.25λ bifilar is a helix formed by rotating two elements of 1.25λ/2 by 270◦

The design parameters, following Kilgus’ notations, are diameter D, pitch distance P, element length Le, and the axial length (i.e. the length of the bifilar along the helix axis). For a half turn bifilar, the axial length is the same as P. For more-turn bifilars, the axial length is determined by the number of turns and pitch. The definition for pitch distance varies among publications and notations, therefore a formula for the axial length from P and turns is not provided here, in order not to cause confusion. Once the number of turns, Le, and D are set in a design, the axial length is readily determined.
B. Quadrifilar Helix Antenna
The radiation properties of a bifilar helix antenna are not particularly attractive to many applications. When two bifilar antennas are excited with phase quadrature as shown in Figure 3-a, however, the resulting antenna, called quadrifilar helix antenna, becomes very appealing to spacecraft applications, with properties listed in the instruction part of this paper.
Some additional remarks may be necessary for describing a QHA. A quadrifilar can be formed by any turn and any length bifilar. Let’s label the two ends of a quadrifilar helix as feed side, as marked in Figure 3-a. It has been found that the four tips a quadrifilar helix with element length of nλ/2, with n being a natural number, can be shorted together, whereas they need to be kept open circuited for Le = (2n−1)λ/4.
A conceptual argument for this open or short arrangement can be made as follows. A bifilar antenna or a square loop in Figure 2-a can be seen as a two-wire transmission line of λ/2 fed from the two terminals. If the end is left open, then the current at the tip and the terminal goes to zero, due to the standing wave formed on the line. This results in a very high input impedance, making it very hard for impedance matching to have an effective radiator. When the two tips are shorted at the end, again a standing wave is formed, but with the current being maximum at the tip and the feed terminal, and a matching can be easily achieved. The voltage at the tip is zero in this arrangement, and therefore one could argue that two pairs of bifilar can be shorted at the tip without interfering with each other. For the λ/4

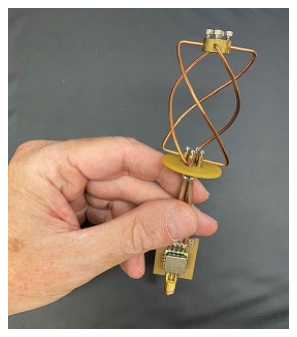
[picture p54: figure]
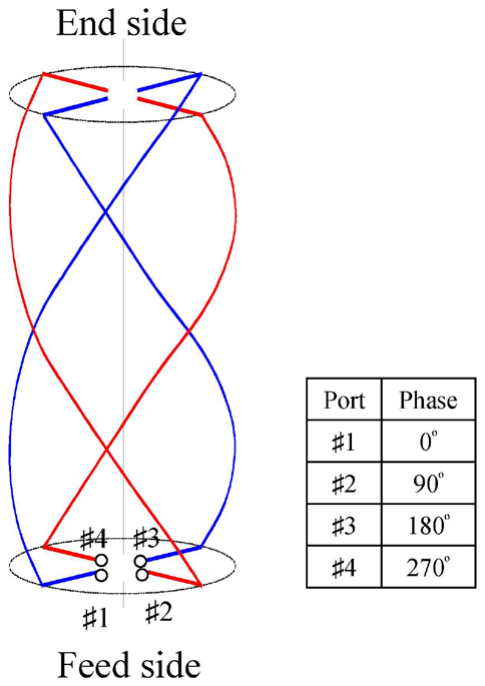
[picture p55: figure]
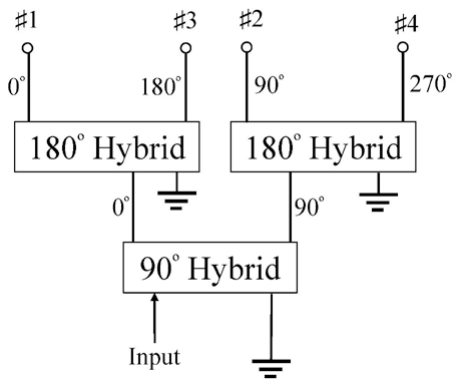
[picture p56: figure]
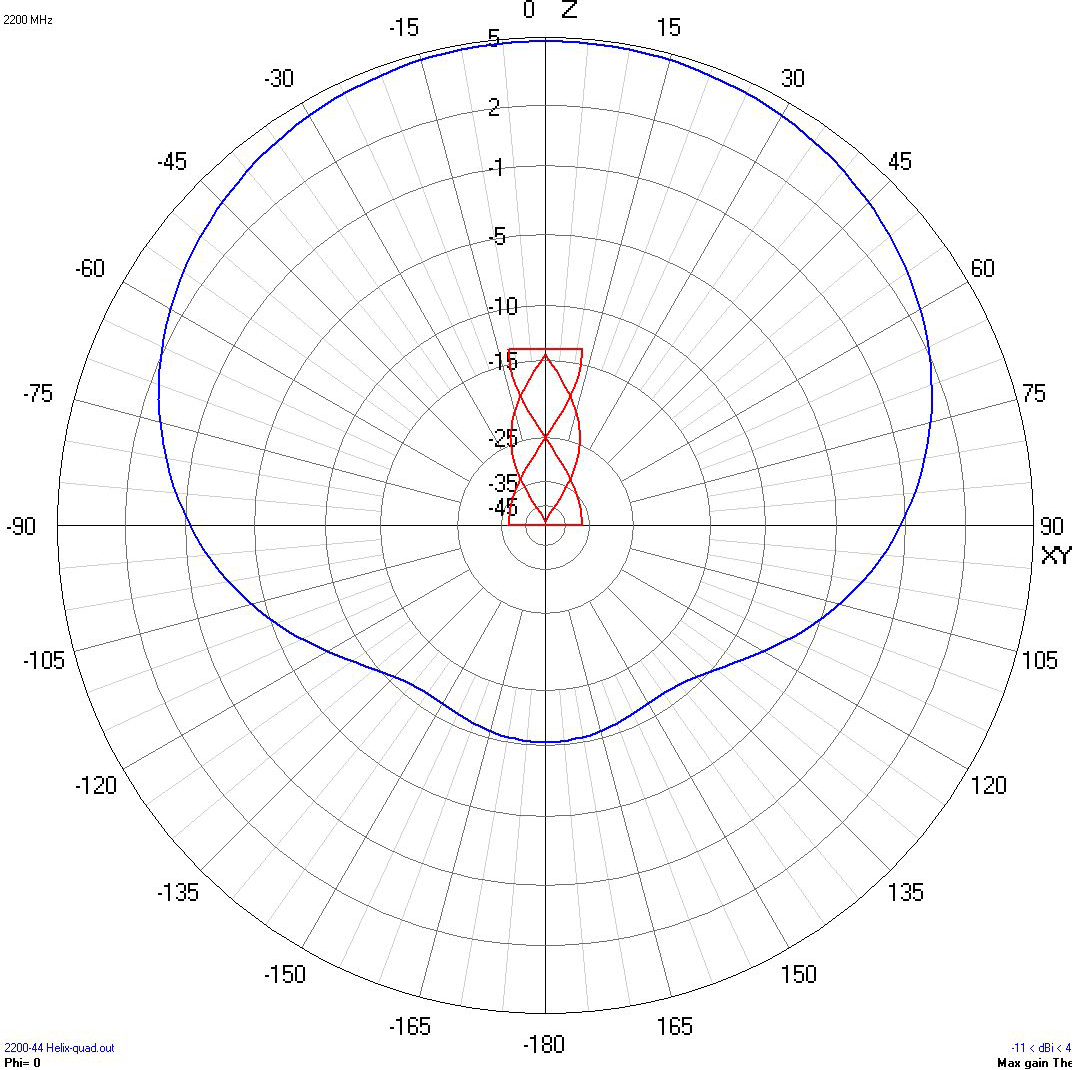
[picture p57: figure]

[Davis] | 3 | 36th Annual Small Satellite Conference

element length, a similar discussion can be made to see that the tip needs to remain open so that the current at the terminal is not trivial. A more rigorous study can be made by accurately computing the current distribution on a QHA, such as by using method of moments, to analyze the behavior of such an antenna. The discussion here is merely intended for an easy visualization.

(a) An Illustration of a Quadrifilar Helix Antenna
(b) An Example Feeding Method Figure 3: Quadrifilar Helix Antenna Formed from Two Bifilar Helices

An example of the feed quadrature is illustrated in Figure 3, where port 1 to 4 lags each other by 90◦

Phasing can be achieved by circuits such as illustrated in Figure 3-b. For a QHA with element length of nλ/2, a ground plane is not necessary, whereas for a quadrifilar λ/4 elements, each element behaves like a monopole, and therefore a ground plane is needed for feeding. In this sense, one may find literature or notes using language such as “does not need a ground plane” for a nλ/2 quadrifilar and “must have a ground plane” for a (2n−1)λ/4 type. Figure 4 is an S band 1/2 turn λ/2 QHA, and it is similar to the one described in reference [5]. As seen, the tips of the bifilars are shorted by a metallic disk with screws to allow one to adjust the element length to tune the antenna to the correct frequency.

Figure 4: An S band Half-turn λ/2 QHA

III. CHARACTERISTICS OF A QHA
A. Radiation Pattern
It has been discovered that 1/4, 1/2, and 1 turn, λ/2 element-length QHA radiate a cardioid-shaped circularly polarized pattern [1]-[6]. The pattern in Figure 5 is created by the author using a free simulator 4nec2 [7], and it is acceptably close to the pattern described by the Kilgus. It has been reported that an optimal radiation pattern and CP is achieved when D = 0.18λ and P = 0.27λ [1], [2].

Figure 5: Radiation Pattern of a Half-turn QHA

An interesting property of a QHA occurs when the element is longer than a wavelength and the turn is more than 1. The radiation pattern of such a longer QHA has been found to be shaped into a conical form by optimizing the axial length and turns [3, 4]. The antenna is circularly polarized too. Figure 6 is the pattern of a 400 MHz QHA quadrifilar helix antenna of 1.5 turns and 1.25 λ element length. It is created with 4nec2 by the author. An antenna pattern with wide beamwidth as the one in Figure 6 with CP is very appealing to satellite application because such an

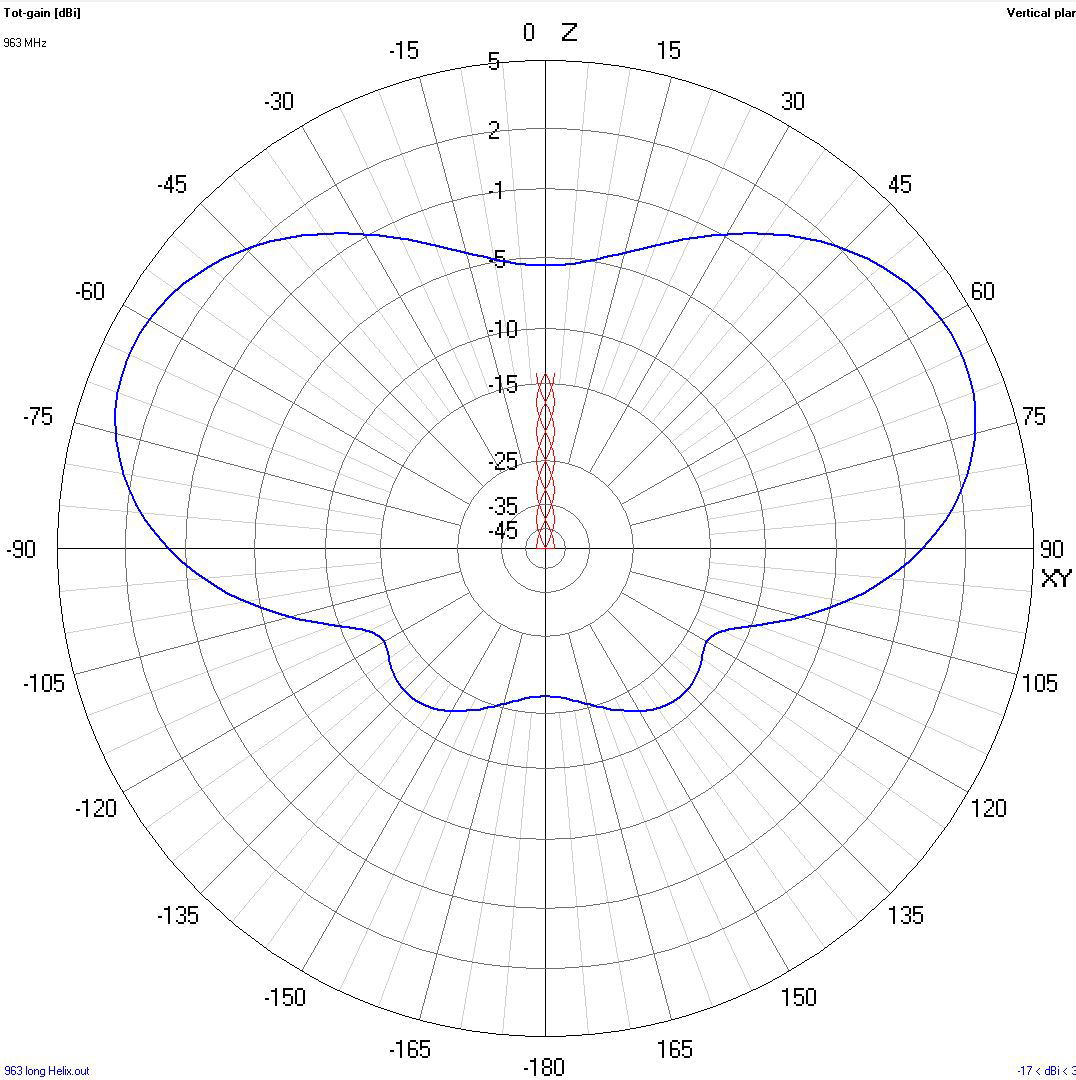
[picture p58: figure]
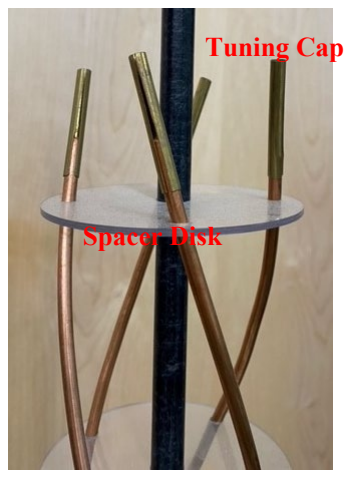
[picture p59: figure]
Tuning Cap
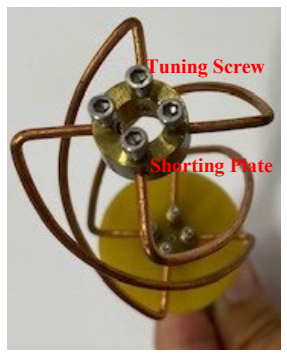
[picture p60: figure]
Tuning Screw

[Davis] | 4 | 36th Annual Small Satellite Conference

antenna helps to maintain an effective communication link for the entire duration when the spacecraft emerges from and goes down the horizon.

Figure 6: Conical-shaped Pattern of a Multi-turn QHA

B. Effect of the Ground Plane
From section II, it is seen that a QHA formed from halfwavelength elements does not require a ground plane. It has been observed that a QHA, whether it needs a ground plane or not, is not significantly affected by the size and location of a ground plane. An explanation is as follows.
From reciprocity, at a direction where antenna radiates more power density, the antenna receives more power or interference. In another words, at a direction where the radiation pattern has a higher value, then the antenna may receive more power flux or couple in more interference from that direction. Accordingly, if a metallic structure with a size that is comparable to or larger than the size of the antenna, is placed at the vicinity of the antenna, then the structure interferes the most with the antenna when it is placed along the maximum of the radiation pattern, and has the minimal effect when placed along the pattern nulls. When the structure is far from the antenna, then the electromagnetic field radiated by the antenna is low upon reaching the object, and the reflected amplitude is accordingly low.
Both cardioid and conical shaped radiation patterns of QHA have relative low back lobes. Therefore, from the principle of reciprocity, one could conclude that a quadrifilar antenna is relatively independent of its mounting location on a satellite.
These properties can be easily verified through simulations and experiment, and is very helpful for a modular design where one could create a QHA without worrying much about whether it will be mounted on the middle of edge of a spacecraft.
IV. QHA EXAMPLES
Several QHAs have been designed and fabricated by the author. Figure 1 shows some of those prototypes, where (a) shows half-turn λ/2 QHAs at 2200 and 400 MHz respectively, and (b) shows three 1.5 turn QHAs formed from 1.25λ elements operating at 2200, 960, and 400 MHz respectively.
For practical tuning purpose, a metallic plate and tuning screws where used for λ/2 QHAs (Figure 7-a), whereas brass caps were utilized for QHAs formed from λ/4 Elements (Figure 7-b). The screws allow one to push in or pull out the tips of the bifilars to tune it to the right frequencies and then short them together. Moving the caps up and down does the same purpose for the opentipped QHAs. It has been found that the tuning cap is a more convenient and practical method, and therefore the longer and multi-turn QHAs built by the author were of open-tip geometry.
(a) (b)
Figure 7: Tuning Mechanisms The phasing of the QHA elements were illustrated in Figure 3. The QHAs built by the author used off-theshelf mini-circuits ([8]) quadrature parts (Figure 8-a), or a 90⸰ hybrid with balun transformers (Figure 8-b). The latter is another implementation of achieving phase quadrature and the circuit illustration is presented in Figure 9 for easy referencing. For multi-turn Le> λ QHA, spacing disks were placed to hold the helical shape (Figure 8-a). The disks can be made from any dielectric material. The ones in Figure 1 and 8 are machined from Lucite glass.
Shorting Plate | Spacer Disk

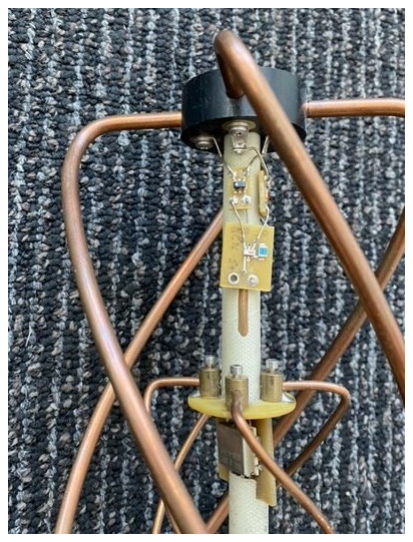
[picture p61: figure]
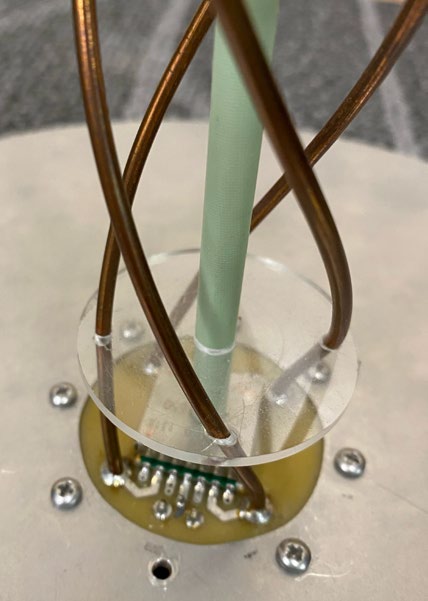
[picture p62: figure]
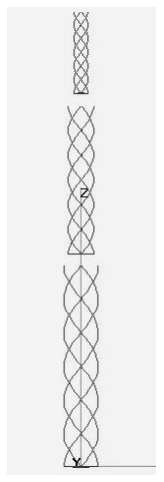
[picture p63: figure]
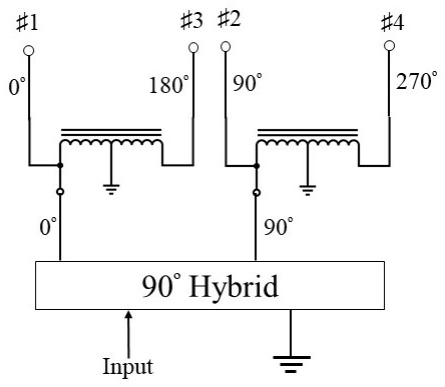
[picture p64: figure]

[Davis] | 5 | 36th Annual Small Satellite Conference
(a) (b)
Figure 8: Tuning Mechanisms

Figure 9: An Alternative Feeding Method

IV. APPLICATION NOTES AND CONCLUSIONS Both a half turn and multiple turn quadrifilar are circularly polarized and therefore stand as favorable antenna solutions for spacecrafts. A half turn 0.5λ quadrifilar helix antenna is slightly longer than a quarter wavelength, with a diameter smaller than 0.1 wavelength. It is circularly polarized and has a smaller size compared to two orthogonal dipoles for a CP. For lower frequencies where one cannot use a patch antenna, a QHA may become a good choice as a low profile antenna. A longer and more turn quadrifilar helix allows one to optimize the radiation pattern to form a conical shape, that is beneficial in reducing the pointing loss in satellite communication links.
The challenge of having quadrifilar antennas on a SmallSat lies on its footprint and deployment. Successful implementation of this type of antenna on small spacecrafts include the S band QHA developed at Surrey Satellite Technology [9] and ones at European

Space Agency [10]. There are also emerging developments of deployable QHAs [1] and commercial prototypes suitable for CubeSats [12].
It should be noted that QHAs are not limited to implementation on spacecraft. They are suitable for ground stations. There are applications where multi-band QHAs are required. In that case, careful stacking of QHAs operating at different frequency is a good solution. Nesting different bands as shown in Figure 1-a and Figure 8-b has been tried but did not yield effective QHAs, due to strong coupling between the elements. From the reciprocity principle explained in section III-B, it is seen that a QHA with conical pattern (Figure 6) has a relative low coupling on the front and back sides. Therefore, stacking multiple QHAs along their axis is as illustrated in Figure 10 is a feasible solution.

Figure 10: Illustration of Multi-band Stacking

References
1. C. Kilgus. Spacecraft and ground station applications of the resonant quadrifilar helix. In 1974 Antennas and Propagation Society International Symposium, volume 12, pages 75-77, 1974.
2. C. Kilgus. Resonant quadrafilar helix. IEEE Transactions on Antennas and Propaga- tion, 17(3):349-351, 1969.
3. C. Kilgus. Shaped-conical radiation pattern performance of the backfire quadrifilar helix. IEEE Transactions on Antennas and Propagation, 23(3):392-397, 1975.
4. C. Kilgus. Resonant quadrifilar helix design. Microwave Journal, pages 49-54, 1970.

[Davis] | 6 | 36th Annual Small Satellite Conference
5. M. W. Maxwell. Reflections, chapter 22: The Quadrifilar Helix Antenna. The national association for Amateur Radio (ARRL), 1991.
6. R.W. Hollander. Resonant quadrafilar helical antenna. TechNote 1999-1, Working Group Satellites.
7. https://www.qsl.net/4nec2/
8. https://www.minicircuits.com (https://www.minicircuits.com/?hsa_acc=1868014922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)
9. https://www.sstl.co.uk/
10. https://www.esa.int/
11. Joseph Costantine, Youssef Tawk, Ignacio Maqueda, Maria Sakovsky, Gina Olson, Ser- gio Pellegrino, and Christos G. Christodoulou. Uhf deployable helical antennas for cubesats. IEEE Transactions on Antennas and Propagation, 64(9):3752–3759, 2016.
12. Helical communication tech. Available at https://www.cubesatshop.com/vendors/ helicalcommunication-tech/.

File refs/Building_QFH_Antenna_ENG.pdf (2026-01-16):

# Building a Quadrifilar Helix Antenna for Undergraduate Researchers

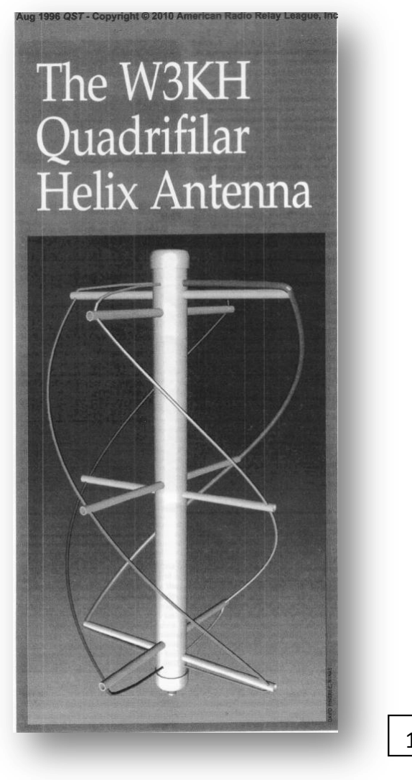
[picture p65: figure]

## Introduction

There are many different antenna designs for capturing images from weather and other low-level, non-geosyncronous satellites. Most of these designs focus on extended range, receiving signals over large arcs, but having null spots directly overhead or at other inopportune locations. The ideal solution to this problem is the extremly effective and efficient Quadrifilar Helix Antenna.

The Quadrifilar Helix Antenna (QHA) is a simple and inexpensive solution to the problem of non-geosynchronous satellite research. This antenna is unique in its simplicity of design and powerful performance compared with standard directional receivers. Once relatively
anonymous, this incredible tool has gained attention recently in many different fields and is particularly valuable for the Global Positioning System (GPS).

While the theory behind such a fantastic antenna is quite complicated, here it has been simplified in order to fascilitate understanding of its construction. For further understanding of antenna theory or the Quadrifilar Helix Antenna in particular, see either Antennas by John D. Kraus or the article in ARRL “The W3KH Quadrifilar Helix Antenna” by Eugene F. Ruperto (listed as superscript 1 throughout this guide for reference purposes)

1

## Parts List

Materials
- BNC attachments for coaxial cable
- Electrical tape
- Several feet of coaxial cable (this will depend on the frequency and size of the antenna you wish to build)
- Several feet of 1/2 inch PVC pipe
- Several feet of 2 or 2.5 inch PVC pipe
- Several feet of copper wire or thin tubing ( length depends on frequency)

Tools
- Ruler or tape measure
- Permanent marker
- Calculator
- Pliers
- Wire cutter
- Wire stripper
- Drill press or electric drill
- X-Acto knife or similar
- Soldering Iron
- Solder
- Solder removing tool (this can be either a wick or a “solder sucker” device)

## A Brief Introduction to Soldering

Warning! The soldering iron and wire joints will become very hot!

Soldering is a necessary and basic skill for any Electrical Engineer, but perhaps you have not had enough experience with it. Here is a brief overview of the proper technique involved in soldering, as well as examples of good and bad soldering.


Soldering is a method of joining two components electrically. This is accomplished by using a soldering iron and solder. Solder is a metal alloy with an extremely low melting point and high capillary action. Often, it contains a resin core which doubles as a flux.

A flux is an acidic substance which serves to slightly etch the surface of whatever component you are soldering. This is useful because it helps the solder to adhere better to the components.Take note though, that soldering is an electrical connection, not a structural weld. Soldering is used to make sure wires will conduct electricity, and will NOT provide substantial strength to a joint.

The first step of soldering is to turn on the soldering iron. There should be a heat control on the power unit, this is important because too high of a temperature can scorch the components you are trying to solder, and too low of a temperature will not be enough to make the solder flow.

Once the iron is heated up (this may take several minutes on larger units), you must touch the iron to the joined components. The goal is to heat the joint untill the solder wire melts on contact with the joint, NOT ON THE SOLDERING IRON! When the joint is hot enough for the solder to melt, the solder will melt into the joint and flow into the various nooks and crannies untill the joint is completely covered. If you fail to heat the joint up enough or only melt the solder on the iron you will leave little drops of melted solder on the joint. This is known as a cold joint and does not supply the necessary conductivity. Below are examples of good and bad soldering. Notice the shiny color in the good soldering connection and the very fluid shape of the solder.

Good Soldering | Bad Soldering


If you find you have used too much solder, you can re-heat the joint and apply either a solder wick-which consists of a braided metal tape- or use a “solder sucker” device which relies on air pressure to remove liquid solder.

### Specific tips for this project

The choice of material for the antenna elements matters greatly. Not on performance, but rather on the ease of construction for this project. The typical choice of wire is copper. Copper is a good conductor and is a popular choice for almost every electrical project, however using large wires leads to additional difficulties. In this case since the wire size is approximately 10 gauge, there is a relatively large amount of copper which needs to be fitted and soldered together. This is a problem because copper has an extremely high heat conductivity. For this reason large copper wires will heat up significantly along their total length before the required joint is hot enough to properly flow the solder.

Aluminum is another possible choice for antenna construction. It is cheaper than copper and less conductive. This is excellent because it means that the aluminum joint can be heated more easily than a comparable copper one. This allows an easier construction of the various connections for the beacon. However aluminum has one large flaw, its tendency to oxidize. Pure aluminum will oxidize in air in several nanoseconds. The oxide layer is a fairly strong insulator which can lead to electrical connectivity problems. However, due to the extremely thin layer of oxide this can be overcome. The severity of this drawback depends on the application, but for this project it should not pose a problem.

Before attempting to solder any connections first brush all the parts to be connected with a steel wire brush, and then apply flux. This will make the process considerably easier if you are using a difficult medium such as copper, and can speed up the process for easier metals such as aluminum.

# Building the Quadrifilar Helix Antenna

## Background Information:

There are a few things that need to be understood before construction can begin on the QHA. Fist and most important is that the dimensions of the antenna are directly proportional to the frequency you wish to receive. Second is that the antenna consists of two sets of loops which are different sizes. This is immensely important as it allows the QHA superior performance by reducing noise and eliminating null spots.

Also necessary is the basic terminology of a standard coaxial cable. It consist of two parts, an inner core wire which is insulated with a dielectric (typically a plastic), and an outer metal braiding. If for some reason you need to splice together a coaxial cable it is a relatively simple matter to connect the core to another core and the braiding to another braiding.

Now that the basics are covered, let’s examine a completed antenna to understand the parts and connections you will need later on.


1

As you can see above, there is a smaller set of armatures located inside of a large set of arms. This is important as these differences in size will determine what frequency the antenna responds to. The connections in the figure to the right are quite important. They form an infinite balun- a method of converting the symmetrical radio signal into a readable impulse to be read by software. One notable feature of this design is that one of the larger loops is replaced with a length of coaxial cable. This can be seen in the diagrams above. This is immensely important to the design and must be kept in mind when measuring the appropriate length of wire.

# Stage 1: Crunching the numbers

The very first thing you must do is understand which frequency you need to receive. Since the antenna you build will be tuned to a single frequency it is vital to consider this first. Additionally, if you plan to use two QHAs at the same time, it might benefit you to make them inside one another so as to avoid a phase difference created by difference in position.

The QHA is easily adapted to almost any frequency and a simple cookbook recipe can be assigned to the various parts. Here are the various values for the antenna segments.

Big Loop | Small Loop
- Height= 0.26 λ • Diameter=0.173 λ • Leg Size=0.560 λ | • Height=0.238 λ • Diameter=0.156 λ • Leg Size=0.508 λ
Step 1: Calculate the wavelength using the following equation. c= λ f In this equation c is the speed of light (often approximated at 3*10⁸m/s) f is the frequency and λ is the wavelength. Additionally, a wire or element diameter of 0.0088 λ is recommended, but failure to use an optimum size will only decrease gain by a few tenths of a decibel.

Once the various calculations are completed it is time to start gathering materials.

# Stage 2: Gathering the materials

Step 2: Gather the necessary materials required by the calculations you have made. Using the example in the above picture, it would require 84.75 inches of smaller diameter PVC, slightly over 24 inches of larger diameter PVC, and approximately 10 feet of wire. These materials should be laid out in an easy to organize fashion, as confusion only breeds mistakes in construction. Below is an example of what the materials should look like.


# Stage 3: Measuring the

Mark the center lines on the central support.

# materials

Step 3: Leaving a few inches of space at either end for structural integrity, mark a starting place for the largest loop. This will be the center of the hole you will drill for that loop. Now measure the distance specified in your calculation of “height” and make another mark on the PVC. You have now marked the center to center distance of your largest loop. At this point it is adviseable to trace a line around the PVC so that the position is easy to see.
Step 4: Next, take the difference in heights between the loops (that is, subtract the small loop height from the large loop height) and divide it by two. This is the distance you must measure from the largest loop towards the center of the antenna (lengthwise). This is so that you have an inner loop which is equally spaced from top and bottom away from the larger loop.
Step 5: As with the large loop, mark a line around the PVC pipe to indicate the center of the small loop. Measure the height specified in your earlier calculations of small loop height from the measurement you just made. Mark the spot. Now you have completed marking the vertical distances of the loops.
Step 6: Finally, measure half the vertical distance for each loop and mark a center line around the PVC. This will be the position of the cross arms which support the antenna in the middle. Measure both center arm marks from the same end. You will notice that both of the center arms will be marked at the same point. This is normal. The center arms will need to be adjust around the center point by an inch or so, just enough so that the supports have clearance through the center. In the case of a dual QHA, both of the center arms were adjusted by approximately ½ inch adjacent to the center line. For more sample measurements on a functioning antenna, see appendix A.

Additionally, if you are constructing an antenna with frequency higher than 300 MHz or so, there may be no need for support arms. In this case continue to mark as usual, but instead of placing supports in the center holes, you will be bending the wire into the center holes in the appropriate shape. For

Caution! It is critical that you measure and cut the wire to precisely the value calculated in the previous section, otherwise the antenna will not be tuned properly.

Step 7: Measure and mark on the wire the distance marked “diameter” on both ends of the wire. This will assist you greatly when it comes time to install it.
Step 8: Finally, pick one spot and use a section of the pipe you will be using to mark a circle around the centerline to indicate the drill point. Repeat on the opposite side being SURE that it is exactly

Adjacent supports are rotated 90 degrees. This is very important.

Note the lack of top and bottom supports. This antenna is small enough to not need them.

aligned on the reverse side. Rotate 90° and repeat with the smaller loop.

Step 9: Work your way up the main pipe this way, rotating each time you come to a new center marking.

Check point: When you are finished marking the support, it should have staggered hole marks and center lines. The picture to the left is an example of what yours should look like when properly marked.

# Stage 4: Constructing the frame

WARNING! NEVER PLACE YOUR HAND BEHIND THE OBJECT YOU ARE DRILLING!

Step 10: The next step is to drill the holes you marked. The easiest way to do this is with a drill press, but if you do not have acess to one, or do not have the necessary skills to use one, an electric dril may be used.

Make sure that the pipe is securely fastened and the drill is positioned precisely in the middle

Step 11: After all the requisite holes have been drilled, carefully inspect them to make sure there are no extra pieces that would stop the cross arms from fitting through.

Caution! it is important to notice that the half-point cross beams will be 90° offest from the end pieces. This means that the large loop holes for the center brace will be on the same side as the small loop holes.

Step 12: Insert the arms through the holes starting from the bottom with a longer arm meant for the larger loop.
Step 13: Once through, measure to make sure both sides extending from the larger pipe are the same length. It is critical that the arms be positioned precisely in the center or else the diameter of the helix will be incorrect and the antenna will not be tuned properly.
Step 14: After all the arms have been measured and adjusted until correct, apply some PVC cement or other adhesive of equivalent strength in order to prevent the arms from moving. Let this dry for several hours before continuing.
Step 15: After the glue has dried, drill small holes the size of the wire you are using near the end of each arm, making sure they are positioned at the distance marked “diameter” in your calculations. The holes should be at approximately a 45° angle left of vertical if viewed from the base. This ensures that the wires when installed will be able to wind counter-clockwise around the antenna when viewed from the bottom.


Step 16: Finally, drill small holes the size of the wire into the size of the central pipe just above or below the top and bottom cross pieces. This is for the wire to enter the central cavity where it can be properly connected. Bear in mind that one of the larger loops will be made out of coaxial cable and as such will need a larger set of holes.

Check Point: At this point the antenna frame should look like the diagram above. The arms should form a staggered cross. The longest arms should be located at the ends of the antenna, and the large loop middle arm should be the lower of the two middle supports. The remaining arms should be support for the smaller loop. If for any reason your antenna is not consistent with the above diagrams, go back and replace arms or drill new holes. Creating new holes in the central support will not affect the performance of the antenna.

# Stage 5: Wiring the antenna

Step 17: Once all the holes are drilled, you must install the wire. This is most easily done by taking a straightened wire and feeding it through the holes, only bending the wire when absolutely necessary to smoothly fit through the cross arms.

Step 18: When the markings you made on the wire indicating the correct diameter length are just beyond or at the top and bottom cross piece bend the ends into the center of the pipe for connection. Repeat this for the 3 arms. The 4th one will require less work as it is composed of coaxial cable.
Step 19: Solder the connections as shown in the wiring diagram on page 4. It is imperative that they be connected as illustrated or else your antenna will not operate correctly.

All the wires at the bottom of the antenna will be connected to the braiding of the coaxial cable, while one of the larger loops at the top and one of the smaller loops will be connected to the center of the cable.

Step 20: Once the appropriate connections are made, wrap them in electrical tape or shrink wrap in order to prevent any accidental breakage from movement.
Step 21: Finally, mount the BNC connector onto the end of the coaxial cable using the instructions included with the part. However if those are missing it is fairly simple to connect the braiding to the outside of the connector, and the center of the cable to the center of the connector.

Congratulations, if all has gone well you are now the owner of a functional Quadrifilar Helix Antenna!

Below is an example of a finished Quadrifilar helix antenna with another antenna nested inside it. This is a complicated project which should not be attempted the first time; however a successful build is quite an achievement for any undergraduate researcher.


# Appendix A: List of Measurements

A functional QHA was constructed with a smaller nested antenna inside it. These were tuned to 150 MHz and 400MHz. They will be labeled as 150 and 400 respectively. All measurements are in inches, with 1 inch = 2.54 cm.

Center support length: 25.5

150 Large loop arm length: 15

150 Small loop arm length: 13

All center measurements from bottom of center support

150 Large loop center locations: 2.5 , 11 ¾ , 23

150 Small loop center locations: 3 5

/16 , 12 ⁵

/8 , 22 ¹
/8

400 Large loop center locations: 9 ¹ /8

, 16 ⁵
/8 (note, no additional armature for middle support)

400 Small loop center locations: 9 ¼ , 16 ¼

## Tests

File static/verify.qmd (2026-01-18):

---
title: QFH calcuation verification
format: html
---

{{< include /_sources/calculator.qmd >}}

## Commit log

2026-01-17 added table printing
2026-01-18 updated landing page
2026-01-19 updated with scad code
    [QFH-Antenna-9165MHz.scad]
